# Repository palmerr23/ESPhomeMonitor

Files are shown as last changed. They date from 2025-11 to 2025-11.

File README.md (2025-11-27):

# ESPhomeMonitor
Hardware for monitoring equipment using HomeAssistant and Raspberry Pi Pico W-based ESPHome installation.

The boards described here are intended to be stacked, with the main Pico W board on top.

A 3D printable case is provided, with custom escutcheons for each input or output board type.

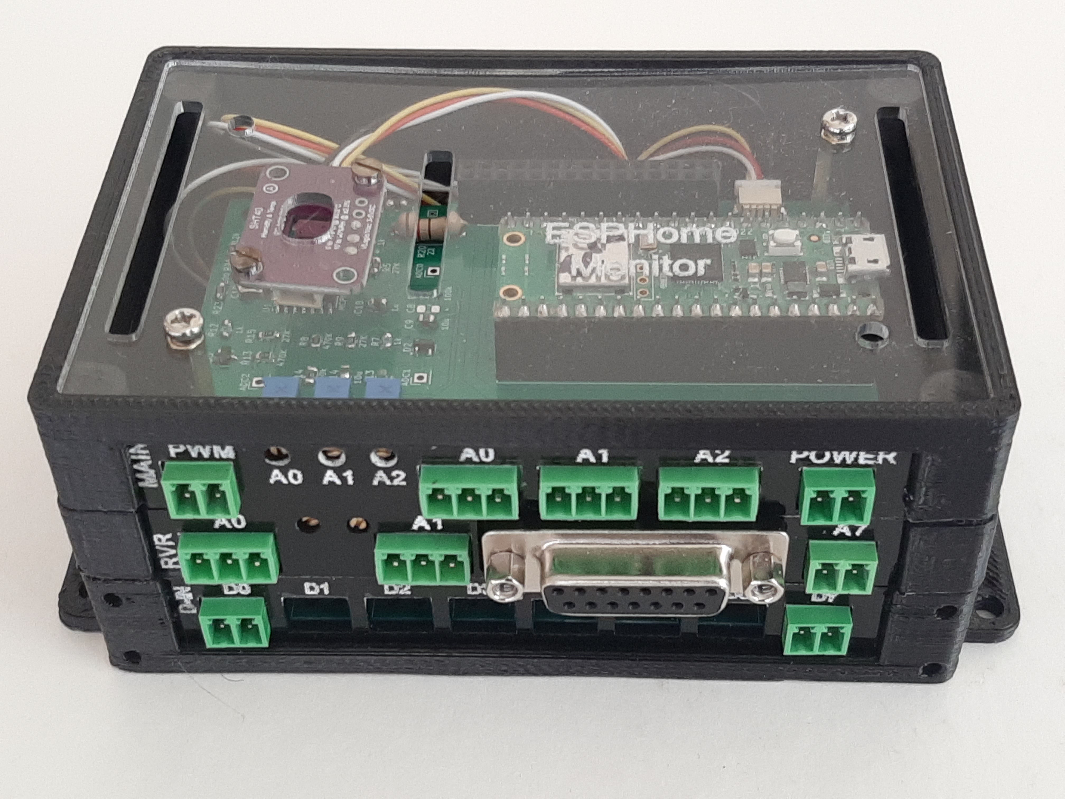
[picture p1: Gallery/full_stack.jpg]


# Boards
+ Main: Pico W, 3 x peak reading analogue inputs (400mV - 48V), filtered PWM output.
+ Analog Input: 8 x analog inputs (3.5V - 48V) 3.81mm pluggable terminals or IDC connector.
+ Analog Input (RVR): A specialised analog input board for RVR TEX150 transmitters and TXRL/RXRL STL.
+ Digital Input: eight channels, opto-isolated or non-isolated. 3.81mm pluggable terminals or IDC connector.
+ Digital Output: eight channels, 4 x opto-isolated + 4 x relays, or non-isolated. 3.81mm pluggable terminals or IDC connector.
+ Expander Board: Second stack and additional 3.3V regulator.

The boards are designed in KiCAD. Gerbers and KiCAD source files are provided.

# Case
A modular, 3D printable case is provided.
+ Base with strain relief.
+ Mid section for additional input and output boards
+ Top section for main (Pico) board.

Each board type has a customised escutcheon panel that slots into the case, designed to be laser-cut from 2mm acrylic.

The case has a top panel with ventilation and mounting points for a SHT-40 I2C temperature and humidity sensor.

The case is joined together with 12mm tapped spacers and 15mm for the main Pico board.

Case files are in STL (body) or SVG (cover and escutcheons) format.

# Documentation and configuration 

+ Technical overview (HomeAssistant Monitoring and Control.pdf)

+ KiCAD design files and an example ESPHome configuration file for each board. 

+ HomeAssistant dashboard configuration is left to the constructor as needs will differ.

ESPHome and HomeAssistant documentation is regularly updated for both platforms:
https://www.home-assistant.io/
https://esphome.io/

The HomeAssistant community forum is a useful place to search for problem resolutions on both platforms.
https://community.home-assistant.io/

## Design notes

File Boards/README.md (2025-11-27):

# ESPhomeMonitor Boards

# Boards

+ Main: Pico W, 3 x peak reading analogue inputs (400mV - 48V), filtered PWM output.
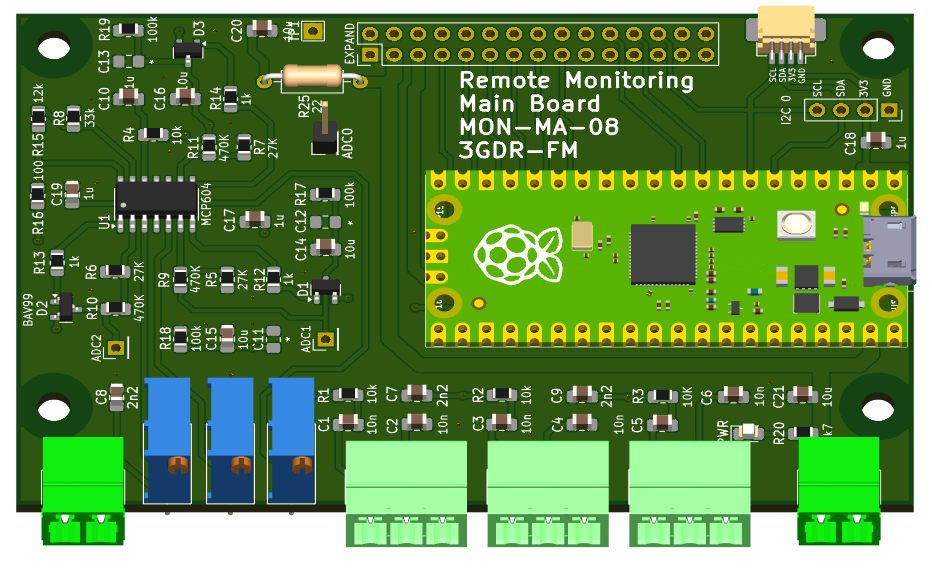
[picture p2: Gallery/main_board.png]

+ Analog Input: 8 x analog inputs (3.5V - 48V) 3.81mm pluggable terminals or IDC connector.
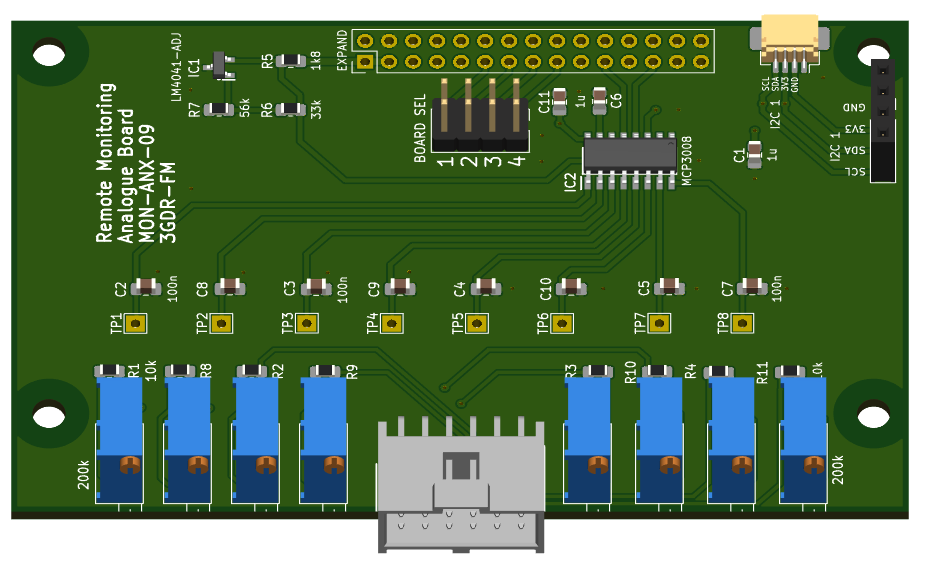
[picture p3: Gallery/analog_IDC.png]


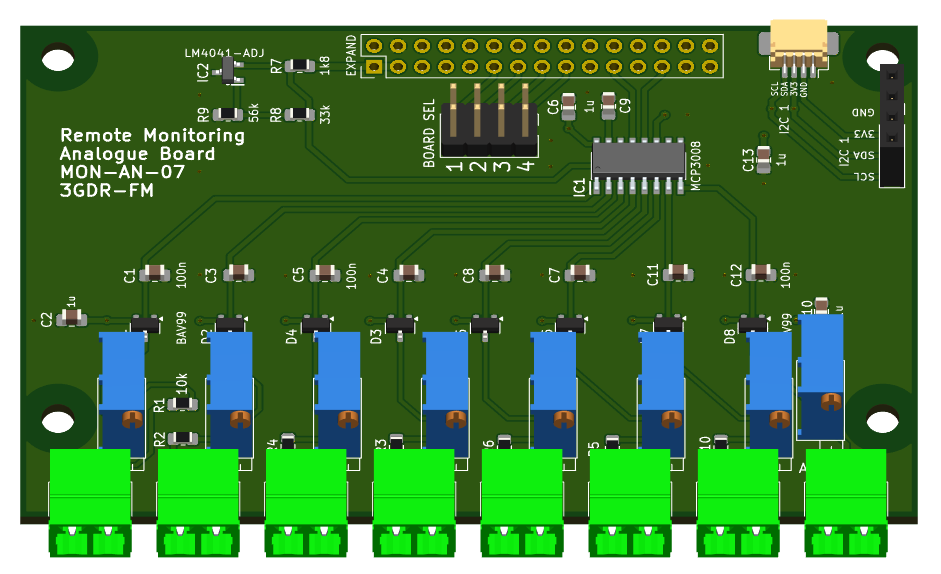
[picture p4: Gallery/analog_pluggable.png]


+ Analog Input (RVR): A specialised analog input board for RVR TEX150 transmitters and TXRL/RXRL STL.
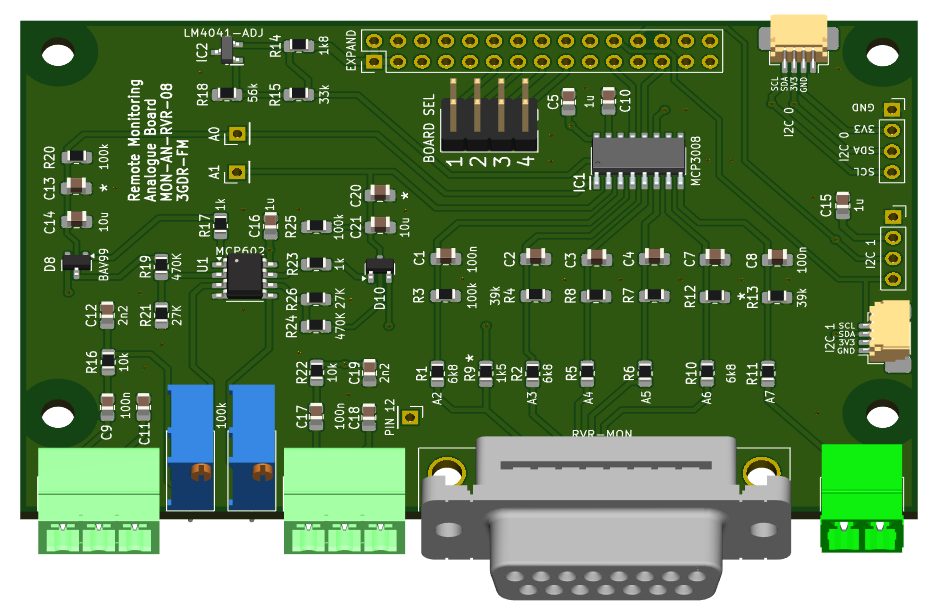
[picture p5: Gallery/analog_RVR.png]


+ Digital Input: eight channels, opto-isolated or non-isolated. 3.81mm pluggable terminals or IDC connector.
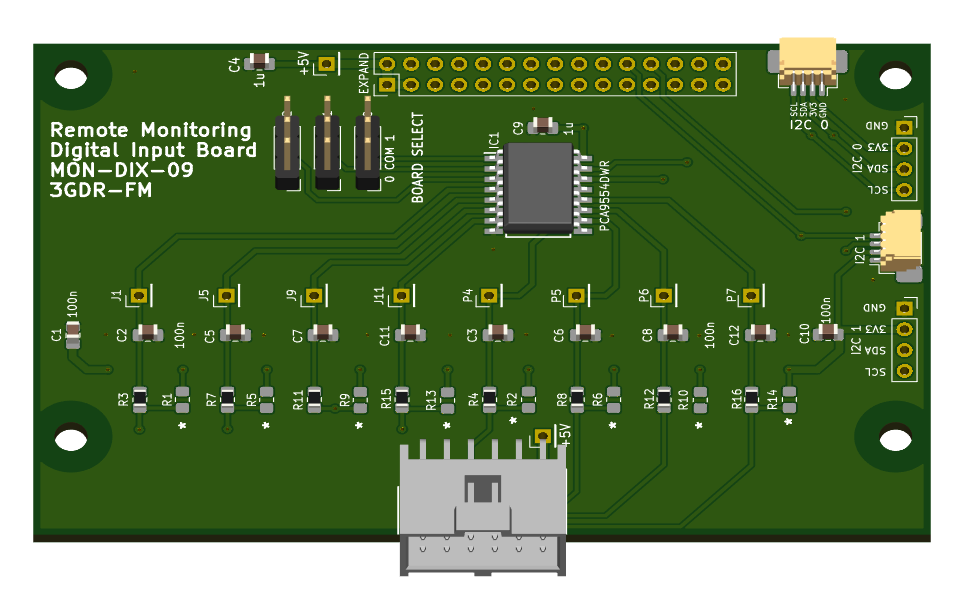
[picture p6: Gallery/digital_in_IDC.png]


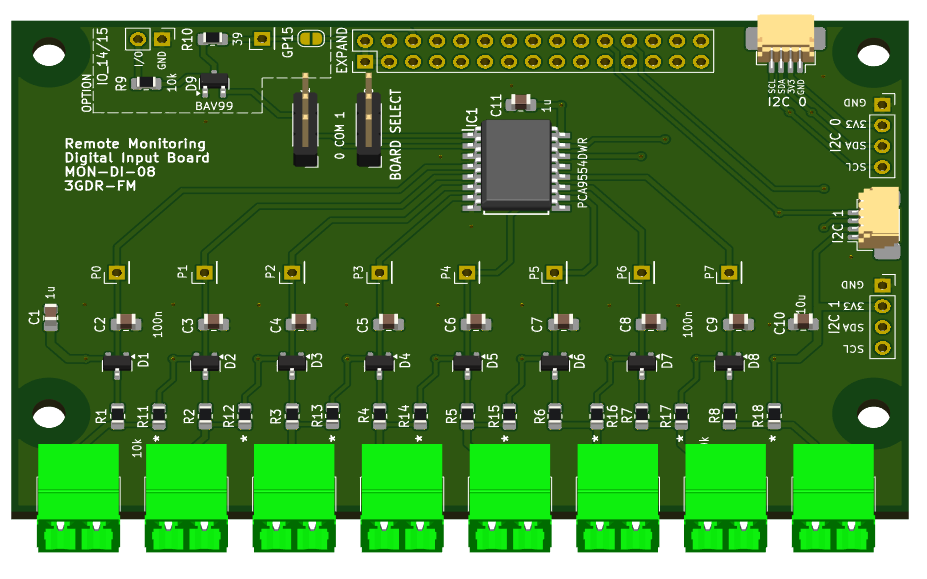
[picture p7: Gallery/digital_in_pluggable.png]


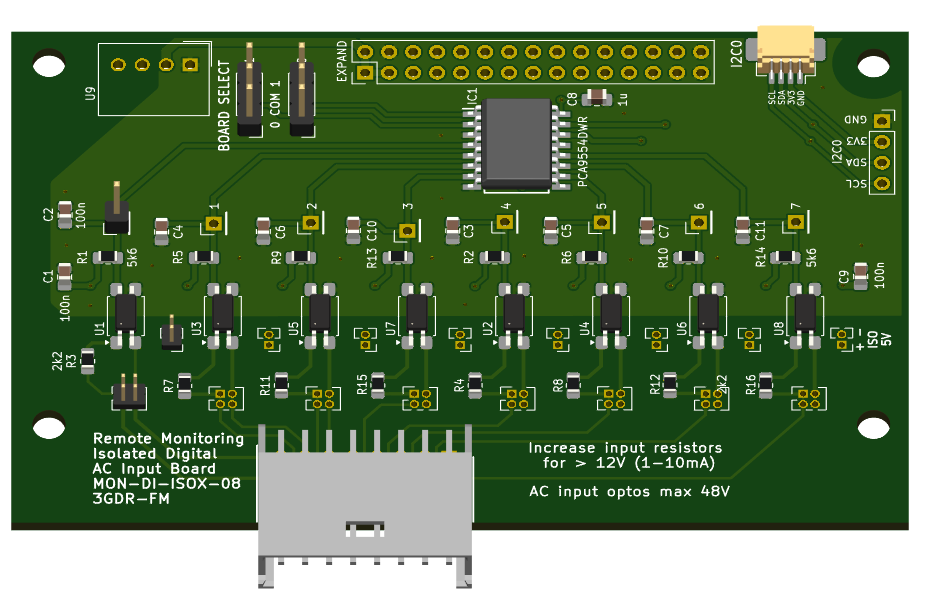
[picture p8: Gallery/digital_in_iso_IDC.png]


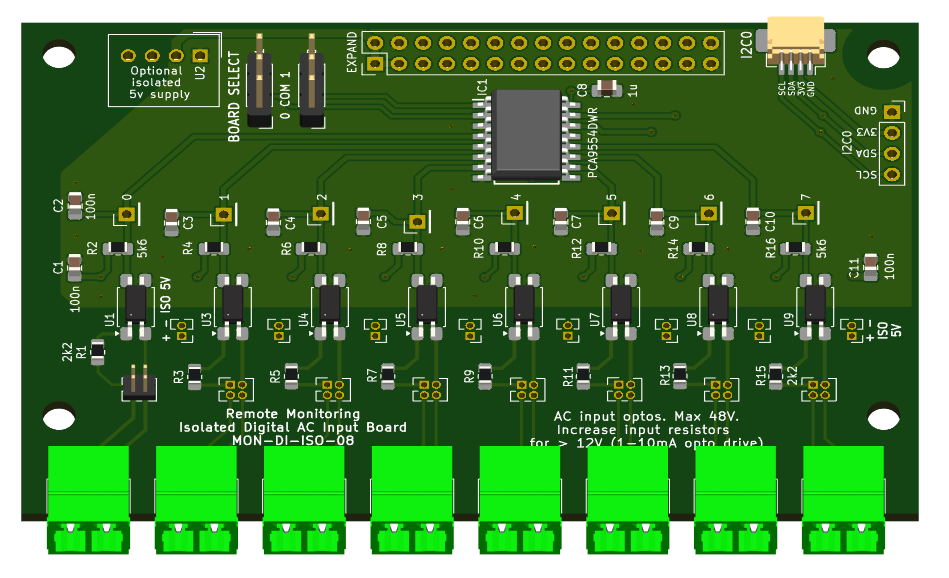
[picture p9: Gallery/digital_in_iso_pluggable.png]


+ Digital Output: eight channels, 4 x opto-isolated + 4 x relays, or non-isolated. 3.81mm pluggable terminals or IDC connector.

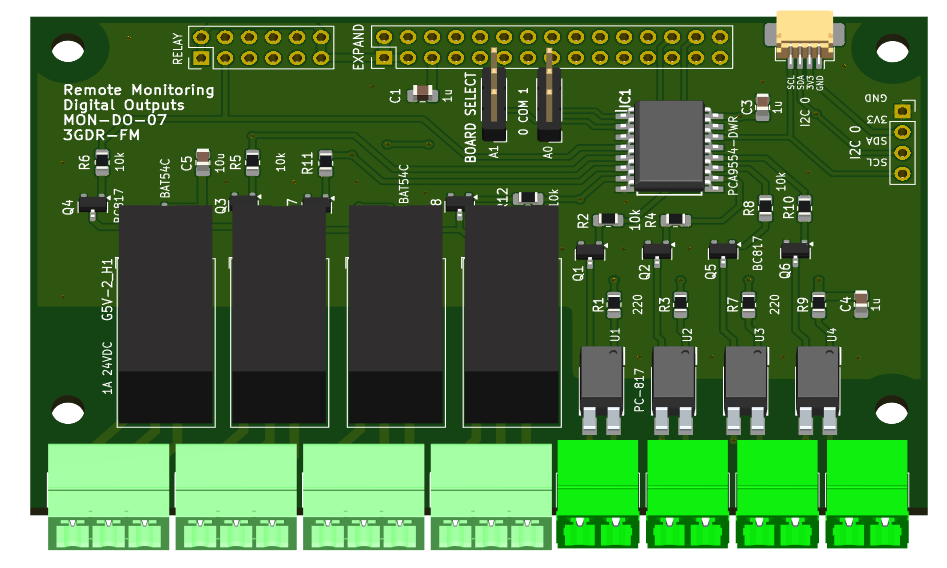
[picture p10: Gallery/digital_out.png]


+ Expander Board: Second stack and additional 3.3V regulator.

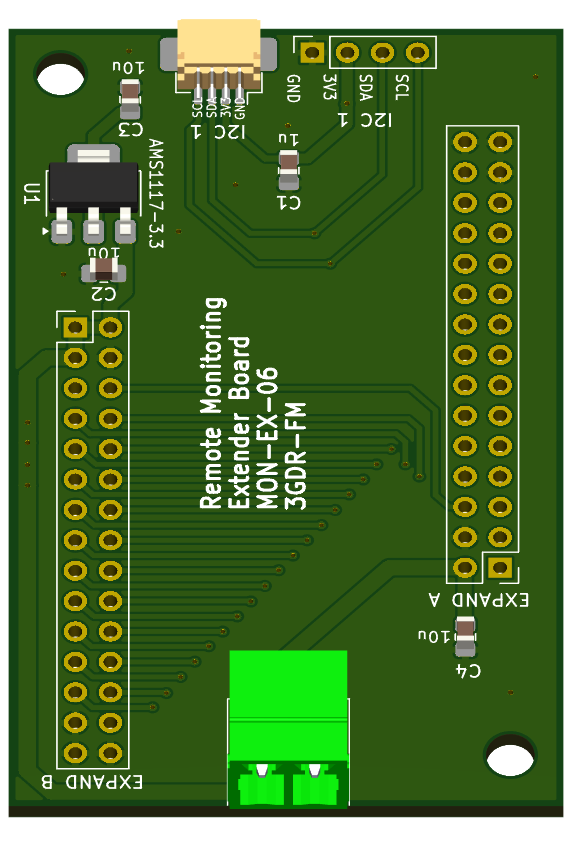
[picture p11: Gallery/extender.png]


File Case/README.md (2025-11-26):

# ESPhomeMonitor Case

The case was designed for 3D filament printing, however resin printing should be OK.

It has three sections: bottom, top and the required number of middle sections.

Top cover and escutcheon pieces are 2mm acrylic.

The base has optional strain relief provided by a length of 3mm bar bent into a U-shape and secured by two bar-holder pieces and 3mm screws and nuts.

The board at the bottom of the case has the long expansion pins on the underside removed.

## Escutcheon pieces 
+ Squeegee white paint into letters on top surface before removing either protective sheet.
+ Remove rear protective sheet and spray paint black.
+ Remove front protective sheet and clean up any extra white paint. Adhesion will be slight, so a soft plastic scraper or fingernail should suffice.

## Top cover

+ Squeegee paint into letters on bottom surface before removing either protective sheet.
+ Remove protective sheets and clean up extra paint.
+ SHT40 mount requires 2.5mm screws and nuts.

## Assembly

+ 12mm x 3mm  tapped spacers between boards.
+ 15mm x 3mm tapped spacer between Pico and top cover.
+ Mount escutcheons over boards before fitting to case. They slide into grooves in the fornt of the case.

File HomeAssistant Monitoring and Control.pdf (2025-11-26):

V1.0 Nov 2025

# PLATYPUS

# IoT Monitoring and Control

This suite of hardware comprises a Raspberry Pi Pico W-based ESPHome main board and a set of stacking daughter boards that support a range of sensor inputs and control outputs appropriate for the monitoring and control of remote equipment, such as a community radio station’s control room or transmitter site.

One or more ESPHome stacks can be connected to a HomeAssistant IoT management base station.

The design is modular and individual boards are stackable.

An Extender board is provided so that stacks can be split into two parts. Alternately, split stacks can be joined with an IDC cable. Cabling to boards using SPI should be kept as short as possible and the SPI frequency kept modest (1MHz) for reliable operation.

While all required sensor and control boards may be stacked on one ESPHome main board, creating several stacks for specific purposes may make more sense for power supply, redundancy, maintenance or operational reasons.

Specific monitoring hardware is included for RVR radio transmission equipment, specifically the TEX150 series of FM transmitters and the PRTL-LCD/RXRL-LCD series of RF studio transmitter links.

The information in this manual is current for:

- Raspberry Pi Pico W – only versions with the CYW43455 WiFi chip are currently supported (Nov 2025).
The Pico 2 W has no formal support at the time of writing (Nov 2025).
- HomeAssistant 2025.11 (HAOS 16.3)
- ESPHome Builder 2025.11

As both HomeAssistant and ESPHome have rapid update cycles, with bug correction based on user feedback, updates should be carefully considered and tested before being applied to the production platform.

Implementation and operation instructions for HomeAssistant and ESPHome are not duplicated in this documentation and community support are available at:

- https://www.home-assistant.io/ and https://community.home-assistant.io/
- https://esphome.io/ and https://community.home-assistant.io/

The repository for this project is: https://github.com/palmerr23/ESPhomeMonitor

- Schematics and board layouts
- Gerber files
- Documentation

## Contents

## Base Station and Satellite

The following components are used in this implementation from among the many available on the ESPHome and HomeAssistant platforms.

- Raspberry Pi running HomeAssistant (HAOS) OS.
- Remote control, monitoring, configuration and updating of HA and ESPHome devices.
- TailScale VPN for remote access.
- Raspberry Pi RP2040 Pico W running ESPHome firmware (Pico 2 W is untested).

### Sensors and Actuators

- See ESPHome.io for all supported devices.
- Analogue – Pico ADC pins and MCP3008 SPI ADCs.
- Digital input and output – PCA9554 series I2C bus expanders.
- SHT4x temperature and humidity sensors (I2C).
- See HomeAssistant.io for all supported devices
- USB webcams (FFMPEG).
- Some IP cameras with ONVIF compatibility (some cameras advertising ONVIF compatibility have failed to register).
- Remote access using TailScale VPN

## ESPHome Stack Overview

### General

- Flexible configuration to suit different needs
- Multiple stacks supported by one HomeAssistant hub on each wireless LAN.
- Flexible connector options:
3.81mm pitch pluggable terminals (Kefa KF2EDG or compatible)
IDC cable
D-sub (for RVR equipment) connectors.
- Single 5V @ 1A supply.

### Main Board

- Pico W running ESPHome OS.
- WiFi connection to HomeAssistant base station.
- 3 channels of peak indicating analogue inputs 400mV p-p, or greater, FSD. Single-ended or pseudo-differential inputs.
- QWIIC connector and pin header for I2C_0.
- Analogue (filtered PWM) 5V output.
- Expansion connector for stacking or daisy-chaining boards.

### Analogue Input Boards

- Eight single-ended analogue channels 3.3V, or higher, FSD.
- Two connector options:
- Pluggable 3.81 terminals
- 12-pin IDC header (3.3V and 5V power)
- QWIIC connectors and pin headers for primary and secondary I2C buses (I2C_0 & I2C_1).
- Four analogue boards (including RVR) maximum, in each stack.

### Analogue Input Board (RVR-specific)

- Eight analogue channels 3.3V, or higher, FSD (set to 4V FSD).
- 6 connected to RVR-compatible DB-15 female connector.
- Jumper from Pin 12 to A1 analogue input for STL MPX signal.
- QWIIC connectors and pin headers for primary and secondary I2C buses (I2C_0 & I2C_1).
- Four analogue boards (all types) maximum, in each stack.

### Digital Boards

- Digital input and output boards use PCA9554 or PCA9554A chips.
- Up to a total of four boards of each chip type can be used in a single stack.

### Digital Input Board - Isolated

- Eight opto-isolated AC inputs (3.3V-12V) with low drive current requirement. Higher input voltages supported with external current-limiting resistors.
- Two connector options:
- Individual 3.81mm pluggable terminal pairs
- 16-pin IDC connector (with optional isolated 5V power).
- QWIIC connectors and pin headers for primary and secondary I2C buses (I2C_0 & I2C_1).
- I2C addresses vary across the compatible chips.
- Four digital boards of a chip type supported in each stack.

### Digital Input Board (non-isolated)

- High impedance (10k) inputs (3.3V-12V).
- QWIIC connectors and pin headers for primary and secondary I2C buses (I2C_0 & I2C_1).
- I2C addresses vary across the compatible chips.
- Four digital boards of a chip type supported in each stack.

### Digital Output Board

- Four SPDT relay outputs (G5V: 1A @ 24VDC), with bypass for external power relays.
- Four opto-isolated outputs.
- Relays and optos may be bypassed if non-isolated connections are acceptable.
- QWIIC connectors and pin headers for I2C_0 & I2C_1.
- Four digital boards of each chip type supported in a stack (I2C addresses vary across the compatible chips).

### Extender Board

- Two back-to-back stacks.
- Alternate 5V supply input.
- Alternate 3.3V regulator for B-connector.
- I2C connectors for I2C_0 & I2C_1.

* The Mains Power Board and Serial Board have not been extensively tested.

### Case

- The modular 3D-printed case comprises
- Base with cable management bar and mounting flanges (4mm screws).
- One middle section per module
- Top section for Main Board (with extra clearance)
- 3mm laser-cut lid with SHT40 environmental sensor mount
Cover plates
- Each module has a 2mm laser-cut side cover plate.
- The cover plates fit into slots in the case.

## Warnings

- Updates should be carefully considered before being applied to HomeAssistant or ESPHome as breaking changes may have been introduced.
- ESPHome Builder and HA updates should only be applied when full testing of the results is convenient.
- A HA backup should be performed before any HA update.
- It is recommended that auto-updates are NOT enabled for add-ons.
- While some inputs and outputs are opto- or relay-isolated, potentials more than 48V different from the board’s ground plane should be avoided.
- Beware fouling the board above if the main (CPU) board is not mounted at the top of a stack.
- When connecting multiple stacks using an IDC cable, care should be taken to ensure correct orientation. Incorrect orientation will connect 5V to GND (pins2 & 4, 27 & 29).
- When selecting output components, consider the start-up behaviour of the ESPHome controller and the RP2040 for connected devices that should receive a known signal at power on.
- Excessive capacitance on the 3.3V supply rail can prevent the Pico starting up correctly. Four boards with 1uF each has proven reliable.
Earthing
Lack of a consistent ‘technical ground’ potential across studio or transmission equipment can cause issues when monitoring is introduced.
- Use opto-isolated digital inputs when ground potentials differ.
- Capacitor couple the ground (unbalanced) or negative (balanced) pin of audio signals being monitored.
- Consider using a separate stack, run from a different 5V supply, if issues persist.

### Table 1: Function Matrix

Board | Inputs or Outputs | I2C | Other
Main (CPU) | 3 x peak detectors (DB9-F) [ADC_0-2] 5V PWM outputs [GPIO 22] | I2C_0 (QWIIC + Header) [GPIO 4 & 5] | 5V power(pluggable) 3.3V @ 250mA supply for other boards
Analogue Input (SPI) 4 boards | 8 x inputs with gain control 12-pin IDC (with +3.3V +55 power) or 3.81mm pluggable terminal options | I2C_0 (QWIIC + Header) I2C_1 (QWIIC + Header) [GPIO 6 &7] | 4 analogue boards maximum per satellite. MCP3008 ADC
Analogue Input (SPI) (RVR adapted) 4 boards | 5 x inputs (DB15-F) 1 x input (pluggable) 2 x peak detectors (2 pin pluggable)
Digital Input (I2C) 4 boards | 8 x direct inputs 14_pin IDC or pluggable terminal options | I2C_0 (QWIIC + Header) | 4 digital boards (input + output) per satellite. May be increased to 8 if PCA9554 and PCA9554A variants are both
4 boards | 8 x AC-input opto-isolated 14_pin IDC or pluggable terminal options Optional isolated 5V supply | I2C_0 (QWIIC + Header) | used. Isolated Digital Input (I2C)

Isolated Digital Output (I2C) 4 boards | 4 x SPDT relay (3 pin pluggable) 4 x opto-isolated (2 pin pluggable) | I2C_0 QWIIC + Header
Non-isolated Digital Output (I2C) 4 boards | 8 x 3.3V digital outputs. 14_pin IDC or pluggable terminal options | I2C_0 QWIIC + Header
Extender | | I2C_0 (QWIIC) I2C_1 (QWIIC + Header) | Alt 5V power input (header or wired) Additional 3.3V regulator option for second stack.

## Stacking PCBs

Stacking PCBs is enabled by mounting 30-pin female headers with long pins on the Expansion connectors of each board. The gap between boards is 12mm (13.6mm including the PCB), which is sufficient to clear the PCB-mounted D-SUB connectors but not the Pico when it is mounted in a header.

When stacking boards, the CPU board should be at the top so that WiFi transmission is unimpeded and so that the top of the Pico does not foul the board above when mounted on a header.

Metal enclosures or lids should be avoided.

Power consumption should be taken into account when stacking boards. The Isolated Digital Out board, particularly, has significant power consumption (480mA @ 5V) with all outputs engaged. If one or more Isolated Digital Output boards are used, the pluggable socket on the Main or Extended board should be used to supply power to the system.

The Pico is capable of supplying 250mA to other boards. If greater current is required, the Extender Board has an optional 3.3V regulator which can supply a second stack.

Boards using the SPI bus should be kept as close to the CPU as practical. The SPI clock speed can be reduced if this is not feasible.

Multiple stacks, sharing a CPU, can be joined using the Extender Board or a 30-pin IDC cable (male or female). Ensure that pin 1 on each stack correctly aligned.
3D printable case
The 3D printable case is designed for a single stack, not using the Extender board.

The bottom-most module should have short pins on the expansion header.

Modules are stacked using 3mm x 12+6mm tapped spacers.

The bottom module is mounted from below the case with 3mm x 8mm metric round head screws and uses a 3mm x 12mm spacer tapped at both ends.

The top module uses a 3mm x 15 + 6mm spacer and the lid is screwed to this, securing the case. It has sufficient clearance for the Main module with the Pico W mounted on headers.

## Part substitution

- Main board pp amps are rail-to-rail, 5V single rail devices with low input currents. Gain-bandwidth product is not critical except in the peak detector circuits where the slew rate contributes to the rise time. Op amps with internal protection diodes protection should be used.
- Either PCA9554 and PCA9554A I2C Bus Expanders may be used in the digital input and output boards. Note that they have different I2C address ranges.
- Pico W: Pico 2 W microcontroller modules are not yet fully tested under ESPHome.

## ESPHome Configuration

Information in the ESPHome documentation is referenced, but not repeated here.

### Startup and Restart Behaviour

During the ESPHome power-on sequence the state of various peripherals is determined by the RP2040 startup behaviour:

- All GPIOs are reset to pull-down state (~50k ohms to GND).
- Soft pull-ups will not be operating on inputs.
- Opto-isolated outputs will be set to open-circuit.
- Peripherals (I2C, SPI, etc) are inactive.
- Analogue outputs (PWM) will be at 0V, although a start-up spike may occur.
- Analogue inputs will have undefined values until the input offset voltage has settled. (~20mS)

After an ESPHome software restart, until the firmware becomes active:

- The ESPHome documentation is unclear on the value of GPIO outputs (GPIO Switch) during startup.
- Analogue outputs (PWM) will temporarily sink towards 0V.
- Peripherals (I2C, SPI, etc) are inactive and will be reset.

When HomeAssistant is unavailable:

- All ESPHome output states remain stable as there are no local ESPHome automations.
- Local ESPHome lambda code continues to run (e.g., serial port logging).
- ESPHome display devices will not be updated if the values are supplied by HomeAssistant.

## ESPHome Main Board

This board should be placed at the top of the stack if the Pico W is mounted on top of the board. WiFi coverage is improved and the Pico, when mounted on headers, can foul the underside of the board above it on the stack.

Alternately, the headers can be placed on the rear of the board, and the pins mounted on the top of the Pico instead of underneath. This configuration is particularly useful for testing daughter boards.

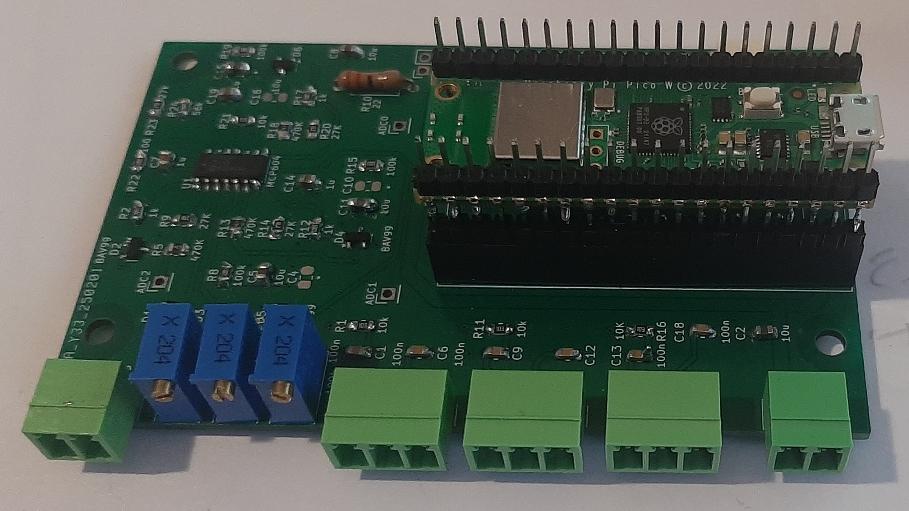
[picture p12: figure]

Boards using SPI should be in the same stack (e.g., power and analogue input) as the CPU board or on a very short IDC extender cable. The default SPI data rate is 1MHz, which can be slowed down further if these boards behave erratically.

The main board hosts the Raspberry Pi Pico W as well as three overvoltage protected, pseudo-differential, peak detecting analogue inputs broken out to a 3-pin 3.81mm pluggable terminals. Their FSD is trimmable via potentiometers from 400mV p-p to more than 12V.

Voltages > 48V should not be applied.

A PWM signal is available via the 2-pin 3.81mm pluggable terminal next to the pots.

Power can be supplied via the Pico’s USB connector or through the 2-pin 3.81mm pluggable terminal at the same end of the board as the Pico’s USB connector.

The Pico W can provide 3.3V up to 250mA to power logic on other boards in the stack. If more current is required, the Expansion board offers a second 3.3V regulator to power a second stack of daughter boards.

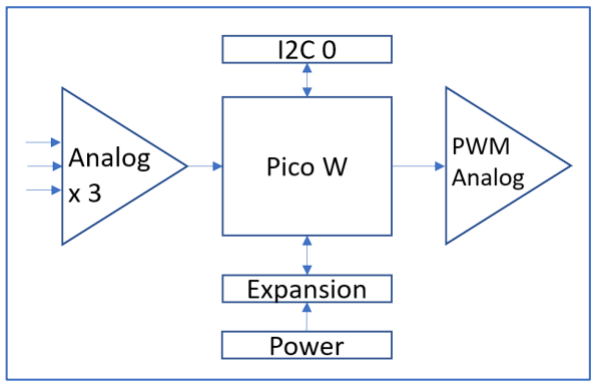
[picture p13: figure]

Main Board Block Diagram

### Expansion Header

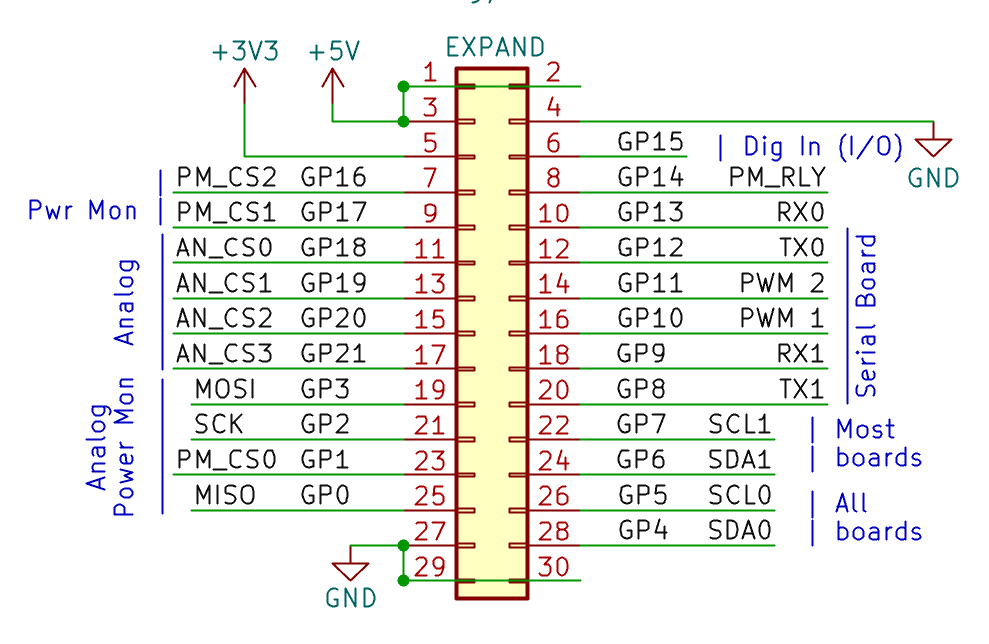
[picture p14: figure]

Expansion header
Table 2: Expansion Header Pins
Pin | Signal | Uses | Pin | Signal | Uses
1 | +5V Power | | 2 | +5V Power
3 | +5V Power | | 4 | GND
5 | +3.3V (250mA tot) | | 6 | GP15* | Dig In I/O
7 | GP16* | Pwr Mon CS2* | 8 | GP14* | Power Monitor Relay
9 | GP17* | Pwr Mon CS1* | 10 | GP13, UART0 RX* | Serial
11 | GP18 | Analog Board SEL0 | 12 | GP12, UART0 TX* | Serial
13 | GP19 | Analog Board SEL1 | 14 | GP11 | Opt. Serial PWM 1
15 | GP20 | Analog Board SEL2 | 16 | GP10 | Opt. Serial PWM 2
17 | GP21 | Analog Board SEL3 | 18 | GP9, UART1 RX* | Serial
19 | GP3, SPI0 MOSI | Analog, Power Mon | 20 | GP8, UART1 TX* | Serial
21 | GP2, SPI0 SCK | Analog, Power Mon | 22 | GP7, SCL1 | Analog, Extender
23 | GP1 | Power Monitor SEL0 | 24 | GP6, SDA1 | Analog, Extender
25 | GP0, SPI0 MISO | Analog, Power Mon | 26 | GP5, SCL0 | Digital In and Out,
27 | GND | | 28 | GP4, SDA0 | Digital In and Out
29 | GND | | 30 | GND
* GPIO 15 is uncommitted in this design.

* GP 0, 1, 8, 9, 12, 13, 14, 16 & 17 may be used for other purposes if the Serial and Power Monitor boards (planned developments) are not used.

### Inputs and Outputs

I2C
Pin assignments are:

SDA 0 GP4
SCL 0 GP5

SDA 1 GP6
SCL 1 GP7

Pull-ups are present on the main board for both I2C buses.

I2C 0 is available on the main board both as a QWIIC (STEMMA QT / Grove / PiicoDev / etc) four-pin JST-SH 1.0mm connector and a four pin 0.1” header.

I2C 1 signals are available via the expansion header on the analogue and digital input boards and the extender board.

SPI
SPI0 is available via the expansion header. CS pins are managed via software.

The Analogue Input boards and Power Monitor boards use SPI.

GP0 | MISO
GP2 | SCK
GP3 | MOSI
GP18-21 are allocated to CS signals for up to four analogue input boards. GP1 is allocated to CS for the (future) power monitor board.

All SPI pins may be reallocated if not required.

UARTS
Both UARTS are presented to the expansion header. They are configurable to any modes and data rates supported by the Pico.
GP8 | TX1
GP9 | RX1

GP12 TX0
GP13 RX0

The pins may be re-allocated if UARTS are not required.

GPIO
GPIOs 15 is available on the expansion header and not used by any of the existing daughter boards – see Table 3.

Any other uncommitted pins on the expansion header may also be used as GPIO inputs or outputs. The constructor needs to take responsibility for protecting the Pico against excessive and reverse voltages. While the Pico’s inputs do include some protection, it is strongly advised not to rely solely on this.

The digital input and output boards include protection as well as providing options for opto-isolation of inputs and relay or opto-isolation of outputs.
Analogue Inputs
Three peak-detecting analogue inputs are available using the Pico’s ADC 0-2 (GPIO 26-28) with a basic FSD of 400mV, trimmable by on-board pots. These inputs translate to 0.0 – 1.0 in HomeAssistant. While the maximum count is 4095 (12 bits), the accuracy (ENOB) is around 9 bits (~512 counts, or 0.2% accuracy).

The inputs are pseudo-balanced and the sensitivity is controlled by the trim pot. The opamp gain is 17 which translates an un-trimmed 390 mV p-p op-amp input to 3.3V output.

If any channel is overdriven erroneous results may occur on other channels, particularly those with small input signals.

If single ended inputs are required, the remote device ground may be connected to the INx― pins or board ground, as desired.

The attack time constant is short (20mS) and the decay time constant is long (2 seconds). They can be changed by varying R2/C4+C5/R8, etc. The Pico’s analogue inputs have ~100k ohm input resistance, so increasing R8 will have limited effect on the time constant.

R1/C1/C2 tailor the frequency response is tailored to an extended speech band: 200Hz to 5kHz.

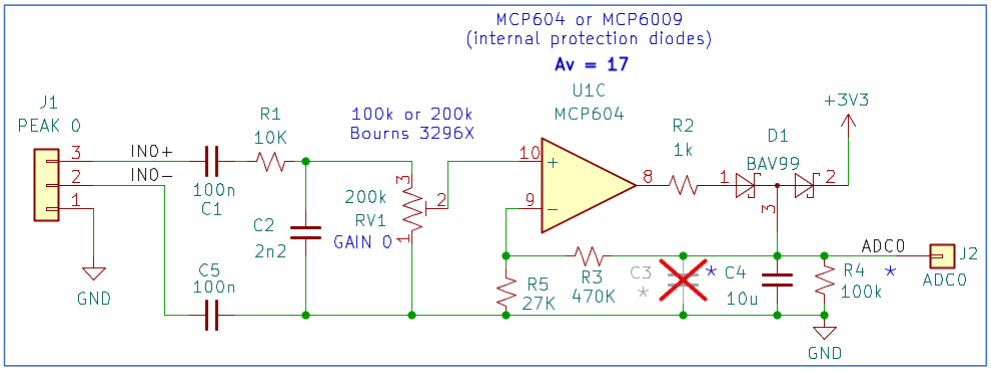
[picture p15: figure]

Example peak detector. C3 may be added to extend the decay time.

The op amps are rail-to-rail, 5V devices with low input currents. The slew rate (GBP) contributes to the rise time. The recommended MCP604 or MCP6009 op amps have internal protection diodes.

ESPHome documentation recommends that digital filtering is applied to all analogue inputs to avoid startup misreads and signal noise. Specifically, the ‘sliding window moving average’ and ‘skip initial’ filters are recommended and included in their example configuration code. https://esphome.io/components/sensor/#skip-initial

# Place in sensor: block

# Pico inbuilt ADC - Main board

- platform: adc
pin: 26
name: "ADC0"
update_interval: 10s
- platform: adc
pin: 27
name: "ADC1"
update_interval: 10s
- platform: adc
pin: 28
name: "ADC2"
update_interval: 10s

Peak Detector Response
The frequency response of the peak detector has been tailored to the speech band, approximating C-weighting.

0

1

2

3

0 | 0.5 | 1 | 1.5 | 2 | 2.5 | 3 | 3.5

Output (V)

Input (Vp-p)

### Peak Detector Response (1kHz)

Vo | Vread

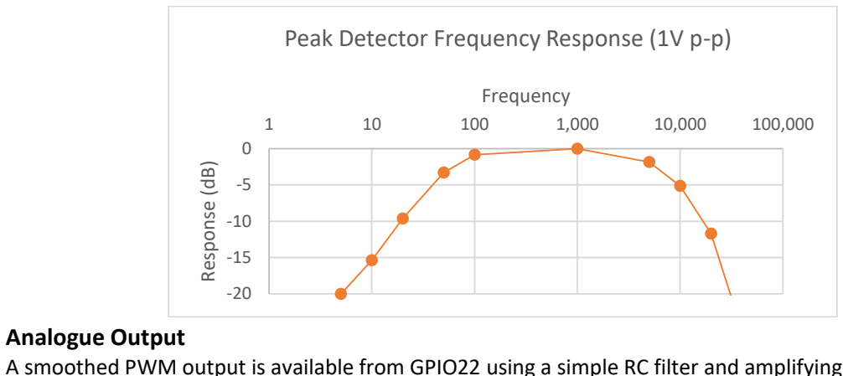
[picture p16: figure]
Analogue Output; Response (dB); Frequency

A smoothed PWM output is available from GPIO22 using a simple RC filter and amplifying buffer.

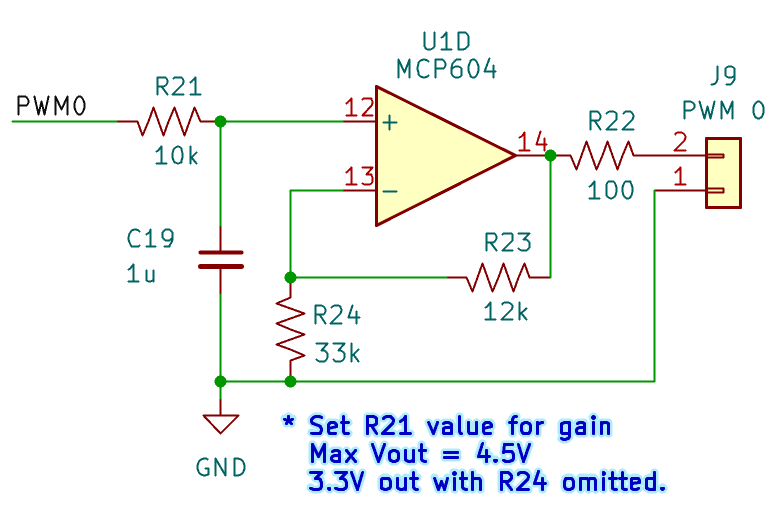
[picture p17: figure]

PWM output buffer

The maximum output level is 4.7V (VCC – 0.3V) with the values indicated for R32/R24 the output is 4.5V @ 100%. Omitting R24 sets the maximum output to 3.3V.

Setting the PWM frequency to 64kHz will provide 10 bits of accuracy and minimise output ripple.
At 64kHz and 50% duty cycle, the ripple is < 10mV p-p.

If lower ripple is required a 100n capacitor may be soldered across R15, providing a second filter pole.

The standard ‘monochromatic light’ platform is configured for linear LED brightness, so Gamma correction needs to be re-set to linear (1.0).

At start-up and restart, the signal will fall to zero.

# PWM output – Main board

output:
- platform: rp2040_pwm
pin: 22
id: PWM_22
frequency: 64000Hz
light:
- platform: monochromatic
output: PWM_22
gamma_correct: 1.0 # align output with pwm % name: "PWM"
id: pwm

Peak Detector Frequency Response (1V p-p)

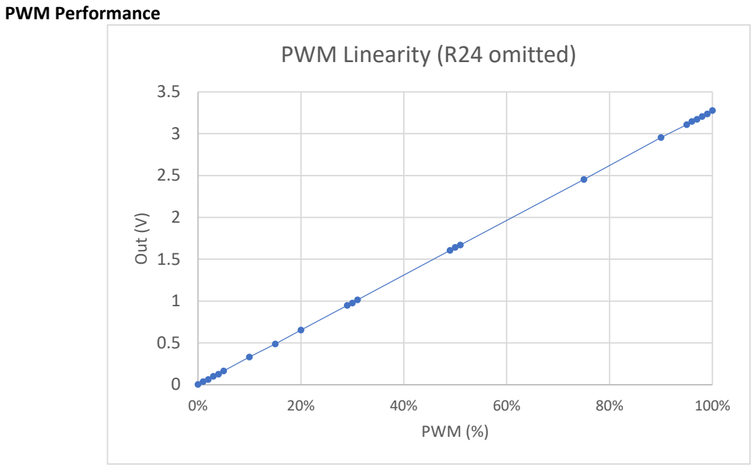
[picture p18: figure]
PWM Performance; Out (V); PWM (%); PWM Linearity (R24 omitted)

Deviation from linear response is < 7mV with a 3.3V FSD output.

### WiFi

The WiFi interface is reserved for communicating with the HomeAssistant base platform.

WiFi credentials are set in the ‘Secrets’ section of the ESPHome Builder tab on HomeAssistant. No additional configuration is required.

### Powering

The Main board consumes less than 20mA, excluding any consumption by devices attached to the I2C interface.

While the unit can be powered via the Pico USB socket for testing, it is recommended that an external regulated 5V supply be connected to the board PWR terminals. The required current can be determined from Table 3. There are additional 5V terminals on the Extender board.

The Pico is capable of providing 3.3V @ 250mA to other boards. If more current is required, a 3.3V regulator is available on the Extender Board which powers the second (B) stack.

### Configuration

The Pico should be configured as described in the ESPHome online documentation. A straightforward approach is to follow the instructions at https://esphome.io/guides/getting_started_hassio which allows firmware loading and configuration of the Pico W from the HomeAssistant browser window.

After the board has been configured and installed using ESPhome Builder, it must be brought on line from the HA Integrations screen.

### Table 3: Daughter Board Current Consumption

Board | 3.3V * excluding connected devices | 5V * excluding connected devices
Main | Can source 250mA | 20mA
Analogue In | 1mA | 5mA
Digital In | 5mA plus 10mA (all 8 optos active) | -
Digital Out | 5mA | 480mA (all 4 relays and 4 optos active)

* Add current drawn by I2C and other connected devices.

## Extender Board

If side by side operation is required, the extender board has two expansion connectors rotated 180⁰ and offset so that the two sets of boards are correctly aligned.

The board has additional 5V input pads.

An optional 3.3V regulator may be mounted on the expander board to power the ‘B’ stack. If this is configured, the Pico should be mounted on the ‘A’ connector and the links on the underside of the board adjusted.

## Analogue Boards

A-D Conversion is provided by an MCP3008 8-input 10-bit SPI ADC. https://esphome.io/components/sensor/mcp3008.html

Three versions are offered with different input connectors:

- 3.81mm pluggable terminals (trimmable on all channels)
- 12-pin IDC cable which also carries 3.3V and 5V power (trimmable on all channels)
- RVR equipment-specific with a DE-15 connector (trimmable peak detectors on channels 0 and 1)

SPI data rates are kept low (200kHz, default is 1MHz) to increase the effective ADC input impedance from 1k ohm to 10k ohm.

A-D Conversion is provided by an MCP3008 8-input 10-bit SPI ADC with 3.3v FSD.

CS jumpers are provided for up to four analogue input boards in a stack.

The native sensitivity of 3.0 V full-scale is decreased by the trimpot, and the 100n capacitor reduces transient sensitivity and provides a charge reservoir for the ADC sample and hold.

The ADC’s internal diodes protect from under and over voltage. R1 keeps the protection diodes within their 250mA current limit for up to 25V when the potentiometers are at their maximum setting.

The maximum recommended input voltage (with reduced gain) is -5V to +48V.

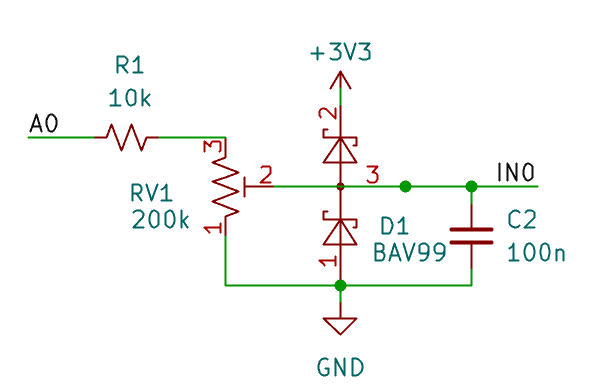
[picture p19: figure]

The LM4041-derived ADC voltage reference is set to 3.3V by resistors R10/R11.

Up to four analogue boards may be used in a stack, by jumpering CS to one of the dedicated expansion pins GP18-21 on the BOARD_SEL header.

### Analogue Input Board (pluggable terminals)

This board has eight single-ended analogue inputs. The ESPHome implementation does not support MCP3008 pseudo-differential mode, as of November 2025.

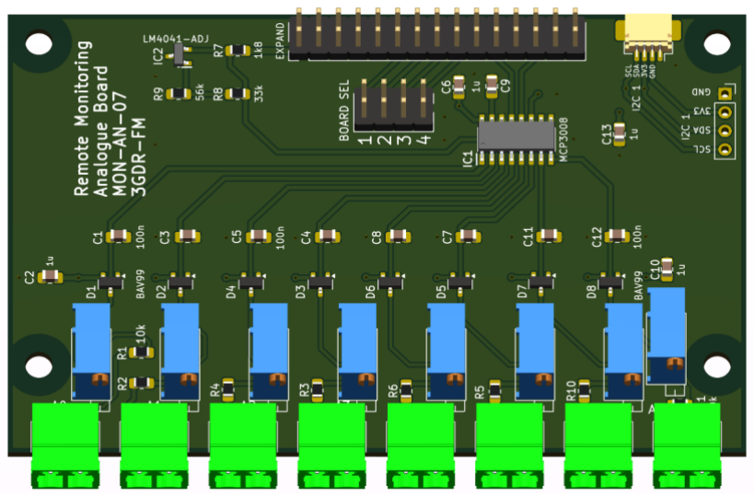
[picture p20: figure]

All inputs have configurable voltage dividers, with a basic sensitivity of 3.3V FSD.

The 100nF capacitors provide a low impedance source for the ADC sample and hold and reduce sensitivity to transients.

The inputs have gain trimmer potentiometers accessible between the input connectors.

CS jumpers are provided for up to four analogue input boards in a stack.

The inputs are presented as 2 x 3.81mm pitch, pluggable terminal blocks.
I2C
QWIIC connectors and pin headers are provided for I2C 1. Configuration
See configuration for the RVR Analogue Input Board.

### Analogue Input Board (IDC)

This board has the same circuit and configuration as the pluggable terminal option, with the inputs presented as a 12-pin IDC header.

3.3V and 5V supplies are provided to power any signal conditioning circuitry on the daughter boards.

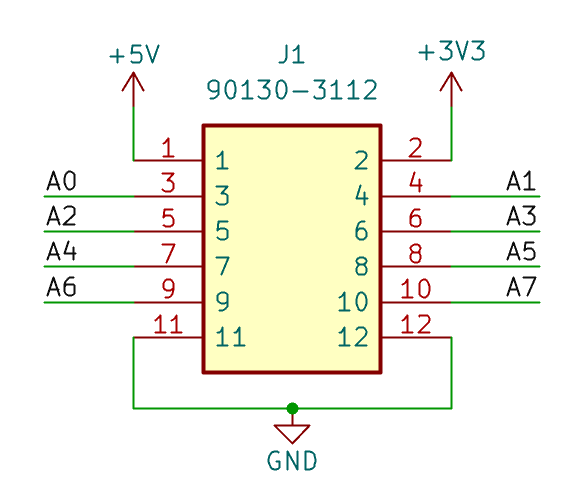
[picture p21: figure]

The IDC connector pin-out is compatible with the non-isolated digital input board.

### RVR Analogue Input Board

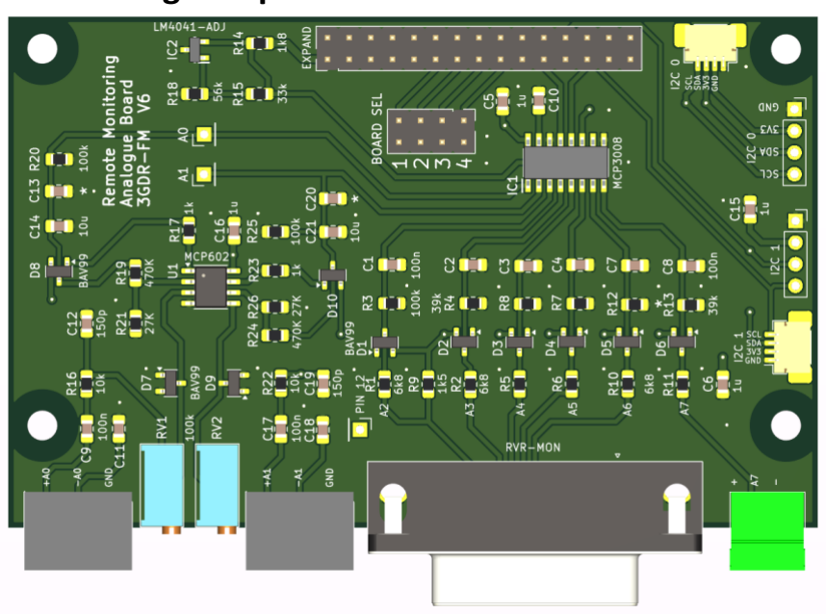
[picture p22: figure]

This board has been designed specifically to interface with RVR broadcast equipment which has a fairly standard monitoring and control interface, presented as a DB-15F connector.

It has five direct-reading inputs tied to specific pins of a DB-15F connector. The remaining DB-15 pins are left unconnected as they have other functions on RVR equipment.

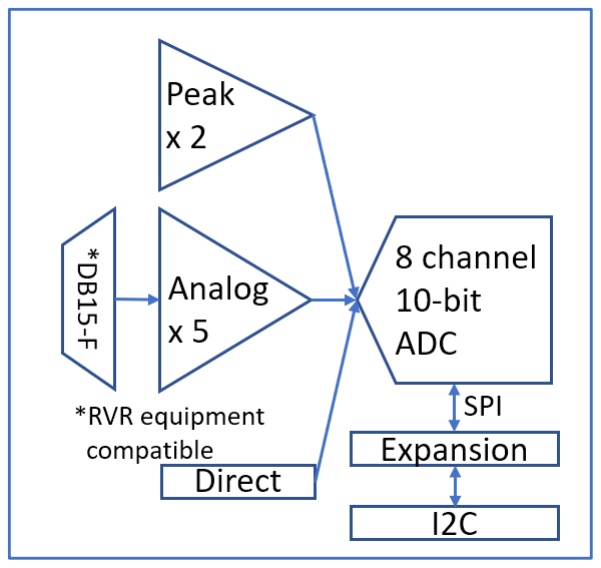
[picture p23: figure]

All inputs have voltage dividers with the default 22k gain resistors providing 3.9V FSD, compatible with RVR analogue monitoring outputs. The 100nF capacitors provide a low impedance source for the ADC sample and hold, and form a low-pass filter (F0 = 250Hz) with the 6.8k input resistors

RVR devices provide an open collector output (PWR_GOOD on transmitters and MUTING_TLS on STLs) on Pin 7 on the DB-15 connector. A pull-up resistor is provided to the 3.3V rail.

Pin 6 is a static analogue signal (PA_CURRENT) on transmitters and a dynamic signal (MPX_LEVEL) on STLs. A patch point to is provided for this signal to be connected to the A0 or A1 peak detectors, if desired.

Of the remaining three inputs, A0 and A1 are peak-reading – with the same configuration as the Main Board.

A0, A1(peak reading) and A7 are presented as 3.81mm pitch, pluggable terminal blocks.

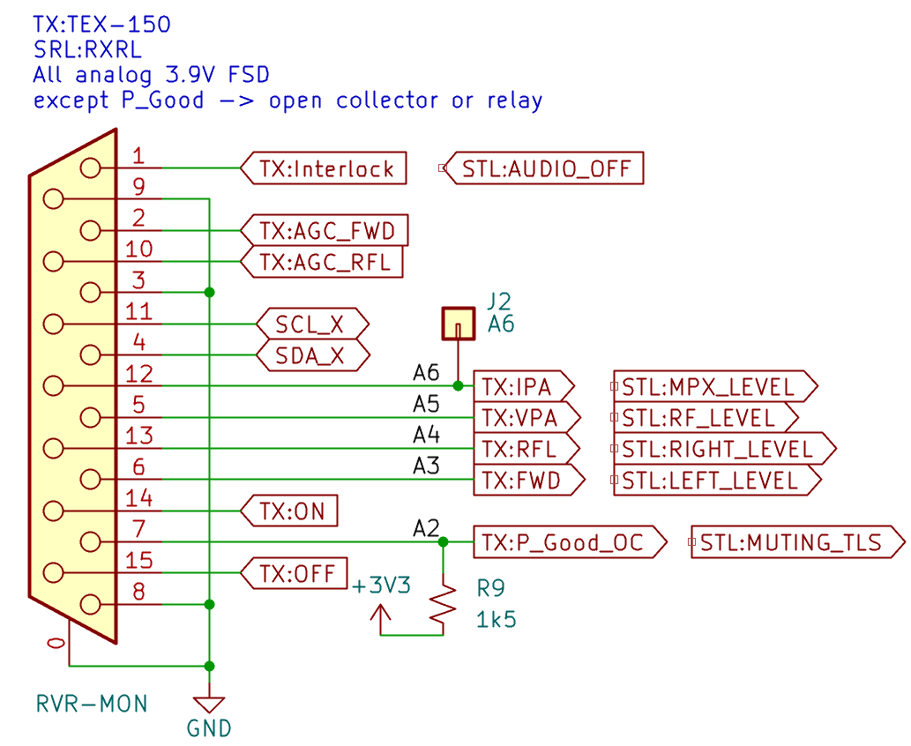
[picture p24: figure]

RVR equipment DB15 pinouts
Pin | RVR FM & STL Transmitter | RVR STL Receiver | Pin | RVR FM & STL Transmitter | RVR STL Receiver
1 | Interlock (control) | Audio Off (control) | 9 | GND | GND
2 | AGC FWD (control) | - | 10 | AGC RFL (control)
3 | GND | GND | 11 | SCL | SCL
4 | SDA | SDA | 12 | IPA | MPX LEVEL
5 | VPA | RF LEVEL | 13 | RFL | RIGHT LEVEL
6 | FWD | LEFT LEVEL | 14 | TX On (control) | -
7 | PWR_Good (OC) | MUTING (OC) | 15 | TX Off (control) | -
8 | GND | GND
- Signals in red are not connected.
- Analogue signals are 3.9V FSD, which represents 100% of the unit’s set value in most cases.
- Pin 7 signals are OC, active low. On-board pull-ups are provided.

The ESPHome documentation recommends that digital filtering is applied to analogue inputs. https://esphome.io/components/sensor/#skip-initial
Configuration

# Place in sensor: block

# Analogue input board

# Channel 0 of the MCP3008.

- platform: mcp3008
unit_of_measurement: "%"
reference_voltage: 3.0
update_interval: 5s
mcp3008_id: mcp0
name: "AD_B0_V1"
accuracy_decimals: 1
id: v1
number: 0
# scale to 100% from 3.3V ref filters:

- multiply: !lambda return 30; # Channel 1
- platform: mcp3008
reference_voltage: 3.0
update_interval: 5s
mcp3008_id: mcp0
accuracy_decimals: 2
name: "AD_B0_V2"
id: v2
number: 1
Auxiliary
QWIIC connectors and pin headers are provided for I2C_0 and I2C_1.

## Digital Boards

The digital input and output boards are compatible with the PCA9554 (and PCA9554A) series of I2C bus expander chips. I2C addresses vary across the range. Four chips sharing the same base address may be used in any stack.

Each board has eight inputs or outputs numbered 0 .. 7.

Inputs or outputs may be logically inverted by code.

https://esphome.io/components/pca9554.html Platform Configuration – all digital boards

pca9554:
- id: dig_in_0
i2c_id: i2c_a #I2C bus previously defined
address: 0x38 | // 0x38 .. 0x3F for Board 0 PCA9554A; 0x20 .. 0x27 for PCA9554
# additional input or output boards are added here:

### Digital Input Boards

Input Configuration
https://esphome.io/components/binary_sensor/

binary_sensor:
# on digital input board 0

- platform: gpio
name: "Input 0"
id: in_0_0
pin:
pca9554: dig_in_0
number: 0 | # 0 .. 7
mode:
input: true
inverted: false # (as required)
# additional inputs or outputs are added here

The ESPHome documentation recommends that digital filtering is applied to all inputs to avoid start-up misreads and signal noise. https://esphome.io/components/sensor/#sensor-filters

Digital Input Board (opto-isolated)
The digital input board has eight opto-isolated inputs which are presented as 2-pin 3.81mm pluggable terminal blocks or a single 16-pin IDC connector.

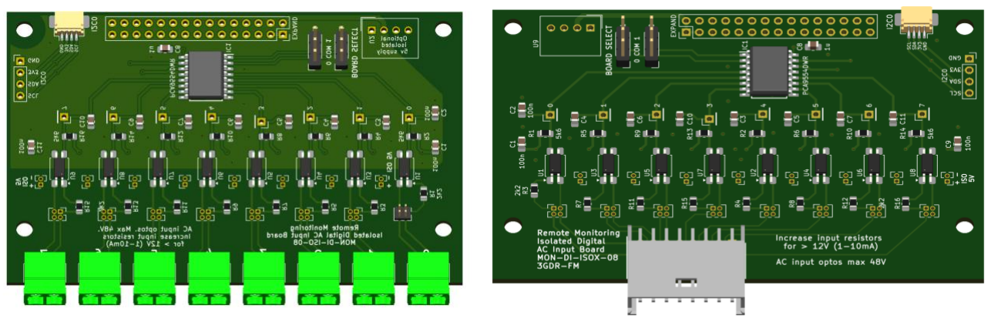
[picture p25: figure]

While the inputs are opto-isolated, potentials of more than 48V difference from the board’s ground should be avoided.

Opto-isolated inputs accept either polarity at a source current of 1mA or more, using AC input opto-couplers with a high (> 100% @ 1mA input) CTR (TLP292, TLP180GB or similar). The PCB footprints have wide pads that can accept either 1.27 or 2.54mm pin spacings.

Jumper blocks are provided to allow flexible configuration of the inputs, along with an access to an optional isolated 5V supply on the IDC variant. The input jumper blocks are linked by default, using fine tracks on the top of the board.

For instance, these jumpers and the isolated power supply may be used to sense a pulled-up switch-to-ground signal. 2.2k pullup resistor is inserted from Viso+ to pin 1 & 3; and Viso- connected to pins 2 & 4.

Both rails of the isolated supply need to be connected to some point in the sensed circuit.


A representative opto-isolated input. The left panel is the default configuration.
The jumpers 1-3 &/or 2-4 may be broken to connect the isolated 5V supply to either pin.
Both rails of the isolated supply need to be connected to some point in the sensed circuit.

If an isolated 5V supply is not required this board may be used with input resistors up to 22k for 48V input.

TLP180GB (high CTR) optos reliably trigger with a LED current of 1mA. With the default 1K ohm input current-limiting resistors the inputs reliably trigger at 1.5V with either polarity inputs, compatible with 3.3 – 5V CMOS logic levels. Above 5V, the series resistance should be increased (either by changing the on-board resistors or by adding eternal series resistors) to ensure the opto’s input current remains in the range 1-20mA.

Input | Trigger voltage | Recommended input resistor (R3+ external) for 4-5 mA operating current
3.3V or 5V CMOS logic | 1.5V | 1k
| 3.3V – 5V | 2.2k
12V | | 3.3k
24V | | 6.8k
48V | | 12k


IDC Header

Digital Input Board (non-isolated)
The digital input board has eight diode-protected inputs and a direct GPIO connector mappable to GPIO 14/15.

It comes with two connector options – individual 3.81mm pluggable terminals or a 12-pin IDC header with the same pinouts as the analogue input board.


With the standard 1k ohm current-limiting resistors on the inputs, the inputs reliably trigger at 2V, and are compatible with 3.3V or greater logic levels. While the inputs are current limited and over-voltage protected, potentials of more than 48V difference from the board’s ground should be avoided.

If reduced current inputs are required, the input resistors may be raised to 47k or greater, as the bus expander has CMOS inputs draw less than 100uA and trigger at 1V and 2.7V (0.3 and 0.8 Vcc).


A representative direct digital input.

IDC Header


The IDC connector pin-out is compatible with the analogue input board

### Digital Output Board (Isolated)

The PCA9554 (or PCA9554A) is used for the digital output boards.

It is recommended that the ESPHome GPIO Switch platform is used instead of the bare GPIO Output.

https://esphome.io/components/switch/gpio

Eight digital outputs are provided, four as SPDT relay contacts and four as opto-coupler OC outputs.

The SPDT relays are Omron G5V-2_H1 (low current coil) equivalents, rated at 24V DC @ 1A or 0.5A @125V AC.

The open collector opto-coupler outputs are active low, and require current limiting resistors which should limit the sunk current to less than 20mA. The maximum VCE0 is 35V.

Voltages of more than 48V above or below the board’s ground plane should not be applied to any terminal.

Outputs are presented as 2-pin x 3.81mm pluggable terminal blocks.


A pin header is also provided to directly drive more substantial relays or SSRs, from outputs 0 to 3. No driver transistor is used, so drive currents should be limited to 5mA. 5V power is available at pins 1, 2, 11 & 12.


Connector: 2x6 x 0.1” pin header

## Specifications

Item | Specification

All boards
Connectors Digital, analogue & 5V power | 3.81 mm pluggable terminals Two and three pin Kefa KF2EDG, Amphenol TJ, etc. 12 and 14-pin IDC sockets
RVR equipment | DB-15F (2-row)

Main
Power supply | Micro USB or 3.81mm pluggable header 5V 50mA + daughter boards
Pico 3.3V supply | Supply: 250mA max (all boards) Use Extender Board for greater current.
Peak-detecting analogue inputs | FSD: 400mV(p-p) or greater Linearity 1% of FSD or better Rise time: 20mS Fall time: 2Sec
PWM output | Range: 0-100% Output: 4.5V @ 100% Ripple: 7mV p-p Linearity; < 7mV deviation (3.3V output)
Expansion connectors | I2C_0 QWIIC and header pins 30 pin Expansion header

Analogue Input (pluggable terminal or IDC)
Number | A maximum of four analogue boards in a stack
Purpose | General purpose analogue inputs.
Connectors | Eight 2-pin pluggable connectors Or 12-pin IDC connector.
Inputs | A0-A7 3.5V (p-p) FSD or greater. Max 50V p-p. 10k ohms or greater. Transient suppression capacitor Input level controls 10-bit resolution, < 0.5 bit INL/DNL
Expansion | I2C_0 QWIIC and pin header I2C_1 QWIIC and pin header
Power supply | 5V < 10mA (3.3V reference) ADC 3.3V supply LM4041 regulator (<1mA) from 5V rail

Analogue Input (RVR)
Number | A maximum of four analogue boards in a stack
Purpose | Optimised for RVR RF equipment (TEX-150 transmitter or RXRL STL)
ADC Sensitivity Linearity | ADC 3.3V FSD 10-bit resolution, < 0.5 bit INL/DNL
Analogue Inputs | A0-A1 Peak detector. See main board specification. A2-A7 3.9V FSD with specified gain resistors 6.8k ohms, 250 Hz LPF A2 Pullup resistor (3.3V) for OC input. A6 Additional patch point near A0/A1
Expansion | I2C_0 QWIIC and pin header I2C_1 QWIIC and pin header
Power supply | 5V < 10mA ADC 3.3V supply LM4041 regulator (<1mA) from 5V rail

Digital Input and Output Boards
Number | A maximum of four Digital Input + Output boards in a stack Eight if a mix of PCA9554 and PCA9554A ICs are used.

Digital Input – Isolated (pluggable terminal or IDC)
Connectors | Eight 2-pin 3.81mm pluggable connectors or 16-pin IDC connector.
Digital inputs | Opto-isolated (PC-817) Trigger: 1-20mA 3.3V - 12V compatible with specified (2.2k) input resistors.
Expansion | I2C_0 QWIIC and pin header I2C_1 QWIIC and pin header
Power supply | 3.3V < 10mA

Digital Input – Non-isolated (pluggable terminal or IDC)
Connectors | Eight 2-pin 3.81mm pluggable connectors or 14-pin IDC connector (includes 5V and 3.3V power)
Digital inputs | 3.3V - 12V input (optional 10k pull-up resistors).
Expansion | I2C_0 QWIIC and pin header I2C_1 QWIIC and pin header
Power supply | 3.3V < 10mA

Digital Output
Relay outputs | SPDT Omron G5V-2_H1 (low power coil) 24v @ 1A
Expansion | I2C_0 QWIIC and pin header I2C_1 QWIIC and pin header
Power supply | 5V < 150mA (all outputs active) 3.3V < 5mA

Extender Board
Power | Alternate 5V input Alternate 3.3V (500mA) supply for EXPAND_B connector.
Expansion | I2C_0 QWIIC and pin header I2C_1 QWIIC and pin header

## Tested I2C Devices

While any SPI or I2C-based sensors and control devices supported by ESPHome may be used, the design has been successfully tested with the following devices.

### Temperature and Humidity Sensor (SHT40)

- The standard configuration is a SHT40 on I2C_0.
- A different ESPHome-compatible sensor, such as the BME680, could be used for a second sensor.
- Alternately, a second SHT40 could be connected on I2C_1.

### BME680 Temperature, Humidity, Barometric Pressure and Gas Sensor

- Temperature, Humidity, Barometric Pressure and Gas Sensor
- Will detect Volatile Organic Compound (VOC) gases such as ethanol, acetone or ethane at moderate concentrations.

### VEML7700 Ambient Light Sensor

- I2C

https://esphome.io/components/sensor/veml7700/

### AM312 PIR Motion Sensor

- GPIO

https://omarghader.github.io/esp32-am312-pir-motion-sensor/

# AM312 connected to a GPIO pin and +5V binary_sensor:

- platform: gpio
pin: 15 # Pin may be changed name: "PIR Sensor"
device_class: motion

### WiFi Webcams

Several ONVIF-compatible webcams were tested (with and without PTZ controls).

Some worked and some didn’t!

https://www.home-assistant.io/integrations/onvif/

## Troubleshooting

The HomeAssistant community forum is a useful place to search for problem resolutions on both platforms.

https://community.home-assistant.io/

The documentation is regularly updated for both platforms:

https://www.home-assistant.io/

https://esphome.io/

ESPHome
Symptom | Cause | Resolution
SPI bus function behaving erratically | Two devices sharing a CS pin | Board jumpers or CS pin definitions.
| SPI bus too long | SPI devices on same stack as CPU board. Slow the SPI data rate.
Poor WiFi coverage | Shielding from boards or enclosure | CPU board to top of stack. Use a plastic enclosure.
Device not appearing in HA Devices or Dashboards after compile and install. | Not enabled | Enable ESPHome device in Settings > Devices > HACS

Home Assistant
Issue | Likely cause | Solution
Dashboard does not update after changing device config or restarting device. | 60 second delay for HA to update entities list. | Reload dashboard page in browser.
New ESPHome device not showing on dashboard or devices list. | Not enabled | Enable ESPHome device Settings > Devices > HACS
New entity not showing on dashboard after refresh. | Not enabled. | Enable on Entities screen menu
Digital input not reading reliably. | Opto current too low. | Reduce input resistance or increase voltage.
Analog peak not reading reliably. | Peak decays before reading. | Add config software filter to read more often and calculate max value over time. Increase C in peak detector circuit. 100uF is a practical maximum.
PWM not linear. | Gamma is set to default (2.8). | Set gamma_correct to 1.0

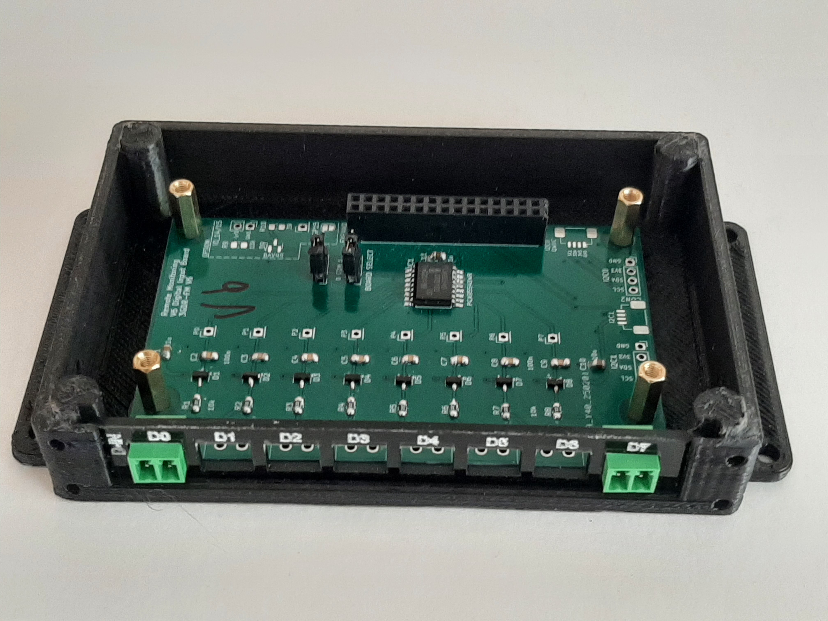
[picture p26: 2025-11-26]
Gallery/one board in base.jpg

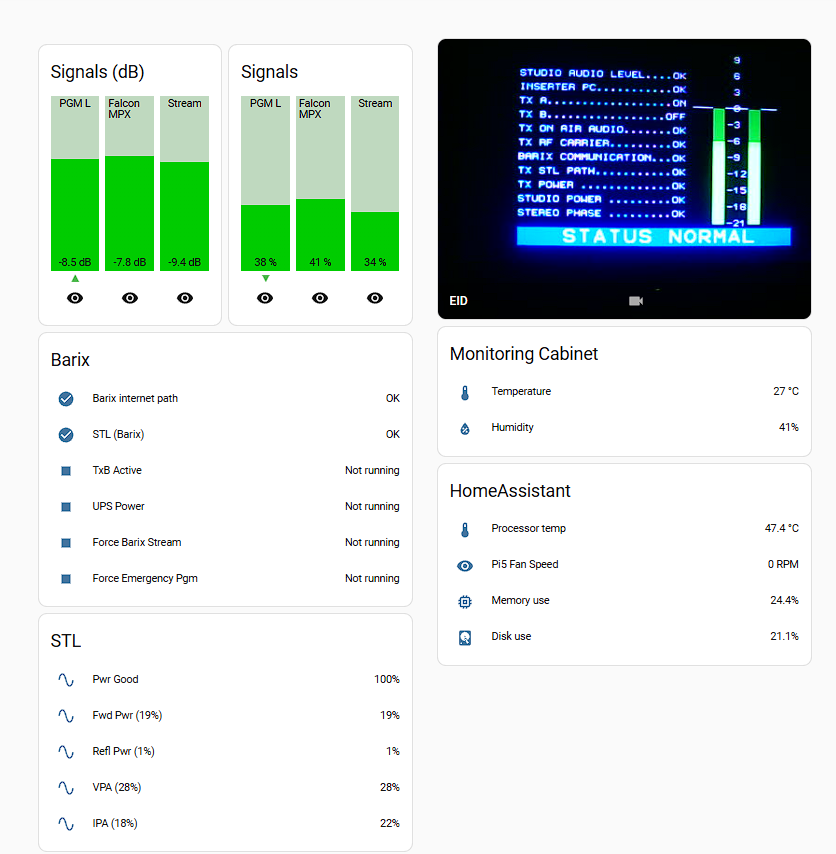
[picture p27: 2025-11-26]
Gallery/Control room remote dashboard.png

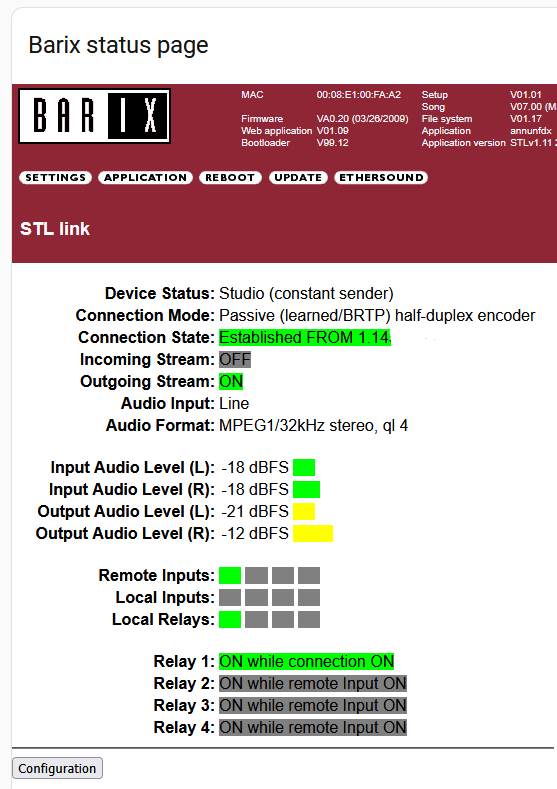
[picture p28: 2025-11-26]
Gallery/Barix Exstreamer STL remote configuration.png

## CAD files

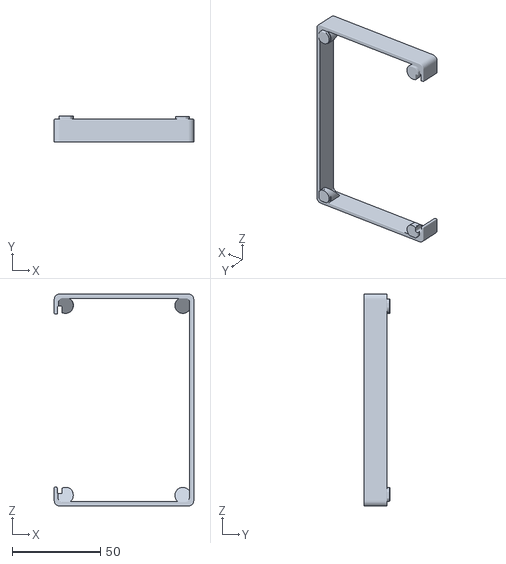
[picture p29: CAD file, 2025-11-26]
Case/middle.stl
79.0 x 14.8 x 120.0

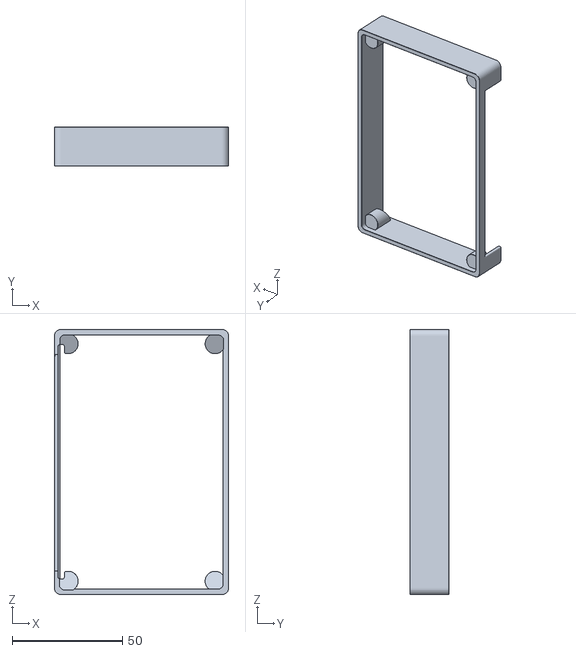
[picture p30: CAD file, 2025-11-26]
Case/top.stl
79.0 x 17.8 x 120.0

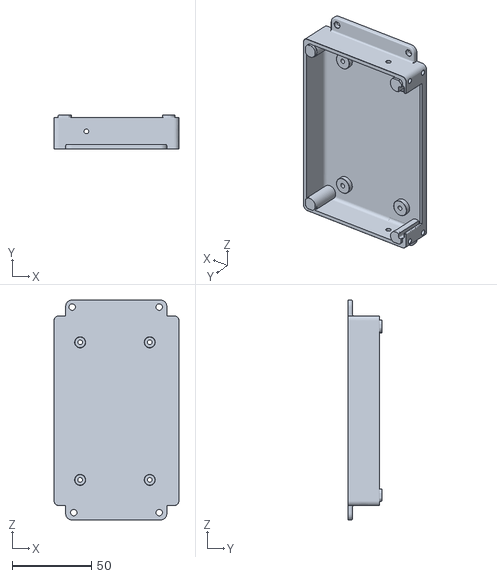
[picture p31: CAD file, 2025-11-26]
Case/base.stl
79.0 x 21.6 x 139.1

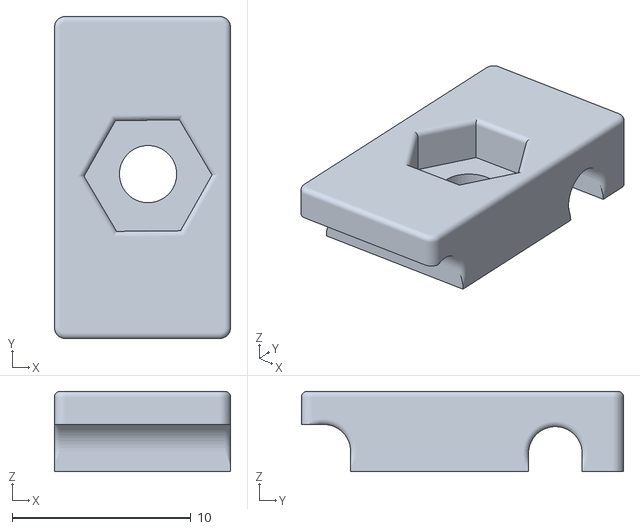
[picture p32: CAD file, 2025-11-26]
Case/bar holder.stl
9.84 x 18.0 x 4.48

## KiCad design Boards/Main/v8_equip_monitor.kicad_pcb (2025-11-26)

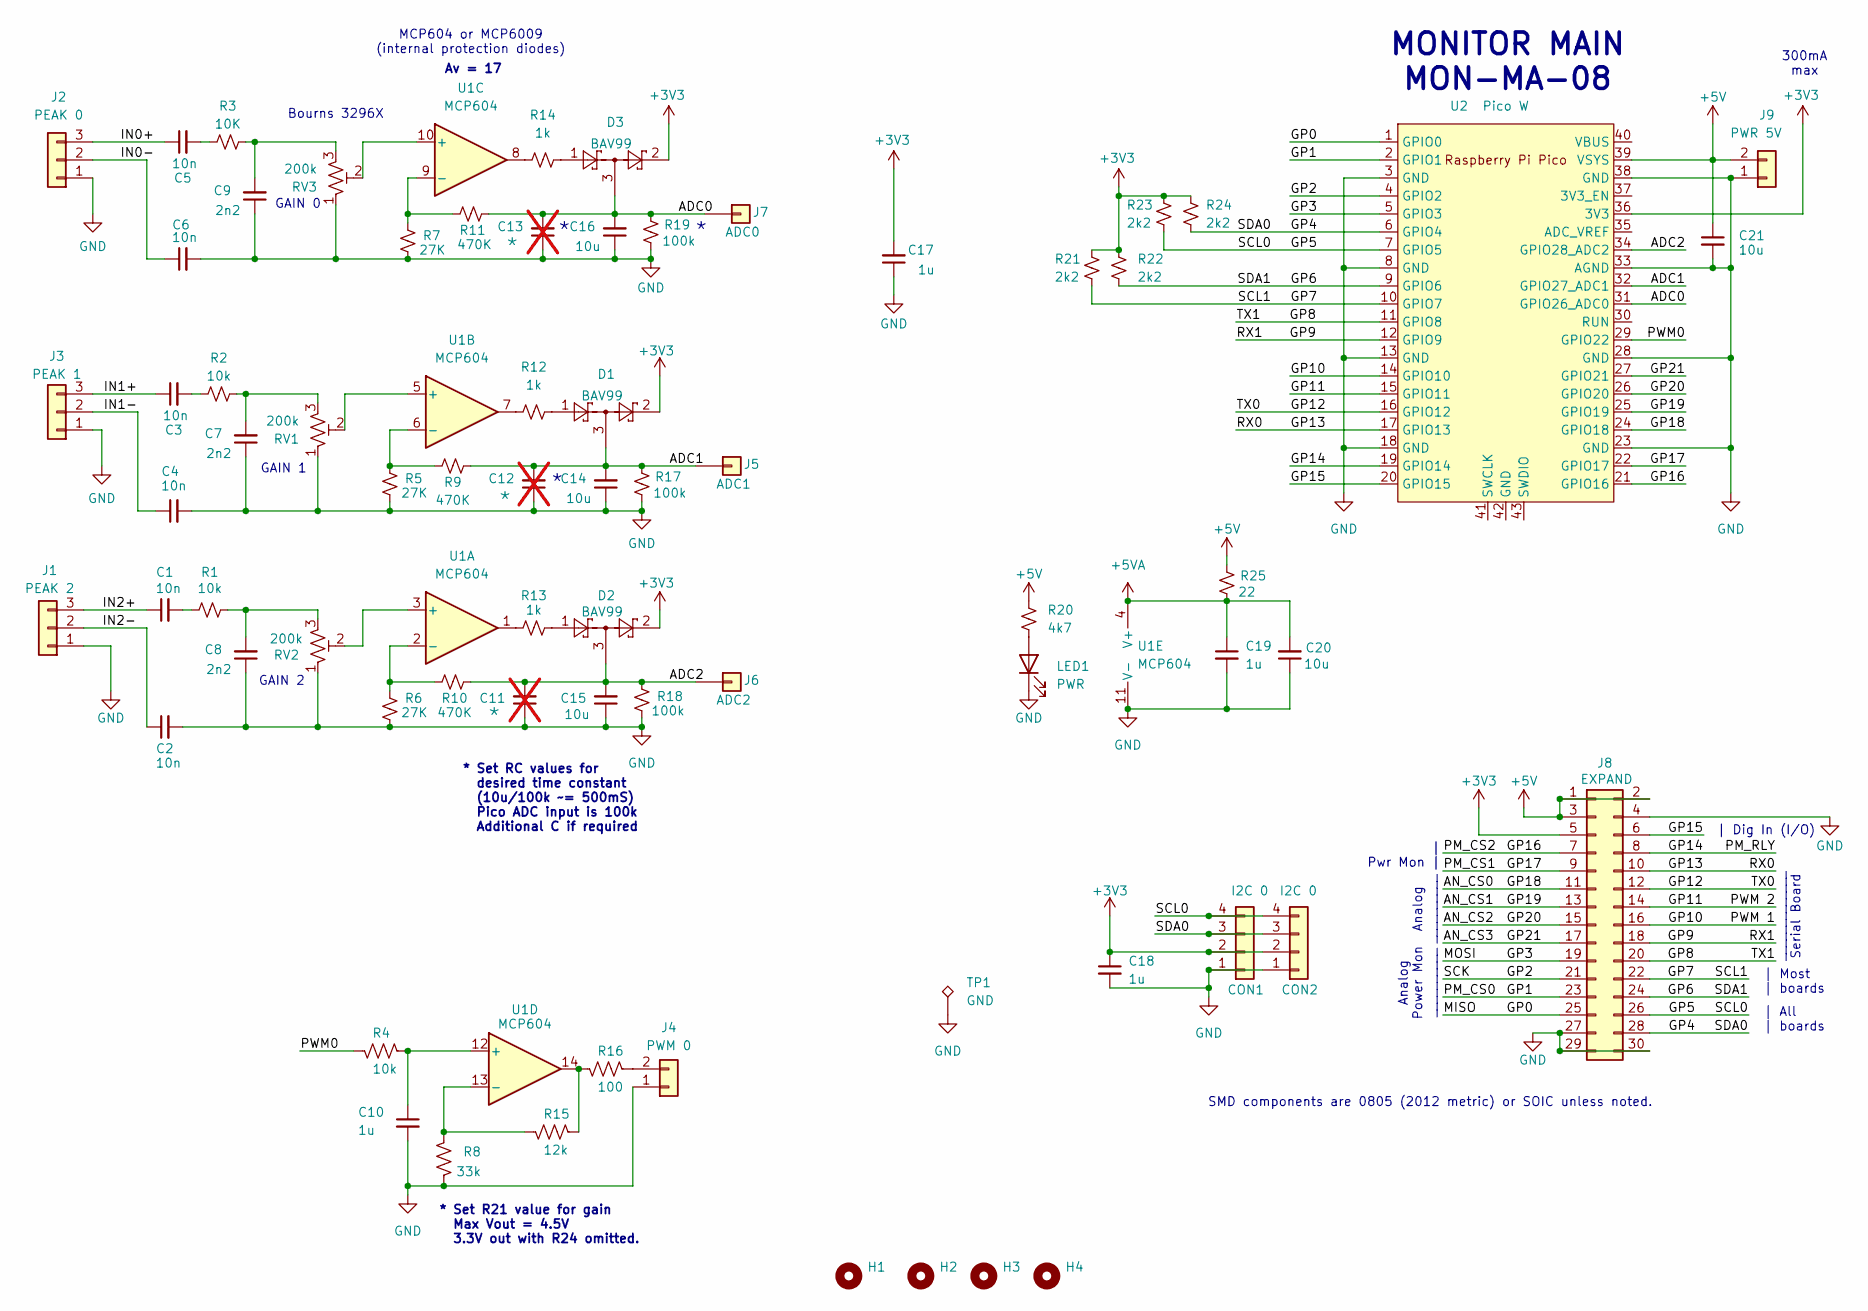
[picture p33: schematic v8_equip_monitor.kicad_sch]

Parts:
C1, C2, C3, C4, C5, C6: 10n; C_0805_2012Metric_Pad1.18x1.45mm_HandSolder
C7, C8, C9: 2n2; C_0805_2012Metric_Pad1.18x1.45mm_HandSolder
C10, C17, C18, C19: 1u; C_0805_2012Metric_Pad1.18x1.45mm_HandSolder
C11, C12, C13: *; C_0805_2012Metric_Pad1.18x1.45mm_HandSolder; not fitted
C14, C15, C16, C20, C21: 10u; C_0805_2012Metric_Pad1.18x1.45mm_HandSolder
CON1: I2C 0; PinSocket_1x04_P2.54mm_Vertical
CON2: I2C 0; JST_SH_SM04B-SRSS-TB_1x04-1MP_P1.00mm_Horizontal_wide_MP
D1, D2, D3: BAV99; SOT-23
H1, H2, H3, H4: MountingHole; MountingHole_3.5mm_no_fill
J1: PEAK 2; K3EDG; Mouser Part Number 649-220110-D031A01LF
J2: PEAK 0; K3EDG; Mouser Part Number 649-220110-D031A01LF
J3: PEAK 1; K3EDG; Mouser Part Number 649-220110-D031A01LF
J4: PWM 0; K2EDG; Mouser Part Number 649-220110-D021A01LF
J5: ADC1; PinHeader_1x01_P2.54mm_Vertical
J6: ADC2; PinHeader_1x01_P2.54mm_Vertical
J7: ADC0; PinHeader_1x01_P2.54mm_Vertical
J8: EXPAND; PinHeader_2x15_P2.54mm_Vertical
J9: PWR 5V; K2EDG
LED1: PWR; LED_0805_2012Metric_Pad1.15x1.40mm_HandSolder
R1, R2, R4: 10k; R_0805_2012Metric_Pad1.20x1.40mm_HandSolder
R3: 10K; R_0805_2012Metric_Pad1.20x1.40mm_HandSolder
R5, R6, R7: 27K; R_0805_2012Metric_Pad1.20x1.40mm_HandSolder
R8: 33k; R_0805_2012Metric_Pad1.20x1.40mm_HandSolder
R9, R10, R11: 470K; R_0805_2012Metric_Pad1.20x1.40mm_HandSolder
R12, R13, R14: 1k; R_0805_2012Metric_Pad1.20x1.40mm_HandSolder
R15: 12k; R_0805_2012Metric_Pad1.20x1.40mm_HandSolder
R16: 100; R_0805_2012Metric_Pad1.20x1.40mm_HandSolder
R17, R18, R19: 100k; R_0805_2012Metric_Pad1.20x1.40mm_HandSolder
R20: 4k7; R_0805_2012Metric_Pad1.20x1.40mm_HandSolder
R21, R22, R23, R24: 2k2; R_0805_2012Metric_Pad1.20x1.40mm_HandSolder
R25: 22; R_Axial_DIN0207_L6.3mm_D2.5mm_P10.16mm_Horizontal
RV1, RV2, RV3: 200k; Potentiometer_Bourns_3296X_Horizontal
TP1: GND; TestPoint_THTPad_2.0x2.0mm_Drill1.0mm
U1: MCP604; SOIC-14_3.9x8.7mm_P1.27mm
U2: Pico W; RPi_Pico_THT_BASIC_INSIDE

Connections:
+3V3: C17.2, C18.1, CON1.2, CON2.2, D1.2, D2.2, D3.2, J8.5, R21.1, R22.1, R23.1, R24.1, U2.36 (3V3)
+5V: C21.1, J8.1, J8.2, J8.3, J9.2, R20.1, R25.2, U2.39 (VSYS)
+5VA: C19.1, C20.2, R25.1, U1.4 (V+)
/ADC0: C13.2, C16.2, D3.3, J7.1, R11.2, R19.2, U2.31 (GPIO26_ADC0)
/ADC1: C12.2, C14.2, D1.3, J5.1, R9.2, R17.2, U2.32 (GPIO27_ADC1)
/ADC2: C11.2, C15.2, D2.3, J6.1, R10.2, R18.2, U2.34 (GPIO28_ADC2)
/AN_CS0: J8.11, U2.24 (GPIO18)
/AN_CS1: J8.13, U2.25 (GPIO19)
/AN_CS2: J8.15, U2.26 (GPIO20)
/AN_CS3: J8.17, U2.27 (GPIO21)
/GP0: J8.25, U2.1 (GPIO0)
/GP1: J8.23, U2.2 (GPIO1)
/GP2: J8.21, U2.4 (GPIO2)
/GP3: J8.19, U2.5 (GPIO3)
/GP4: CON1.3, CON2.3, J8.28, R24.2, U2.6 (GPIO4)
/GP5: CON1.4, CON2.4, J8.26, R23.2, U2.7 (GPIO5)
/GP6: J8.24, R22.2, U2.9 (GPIO6)
/GP7: J8.22, R21.2, U2.10 (GPIO7)
/GP8: J8.20, U2.11 (GPIO8)
/GP9: J8.18, U2.12 (GPIO9)
/GP10: J8.16, U2.14 (GPIO10)
/GP11: J8.14, U2.15 (GPIO11)
/GP12: J8.12, U2.16 (GPIO12)
/GP13: J8.10, U2.17 (GPIO13)
/GP14: J8.8, U2.19 (GPIO14)
/GP15: J8.6, U2.20 (GPIO15)
/GP16: J8.7, U2.21 (GPIO16)
/GP17: J8.9, U2.22 (GPIO17)
/IN0+: C5.1, J2.3
/IN0-: C6.1, J2.2
/IN1+: C3.1, J3.3
/IN1-: C4.1, J3.2
/IN2+: C1.1, J1.3
/IN2-: C2.1, J1.2
/PWM0: R4.1, U2.29 (GPIO22)
GND: C2.2, C4.2, C6.2, C7.1, C8.1, C9.1, C10.2, C11.1, C12.1, C13.1, C14.1, C15.1, C16.1, C17.1, C18.2, C19.2, C20.1, C21.2, CON1.1, CON2.1, J1.1, J2.1, J3.1, J4.1, J8.4, J8.27, J8.29, J8.30, J9.1, LED1.1 (K), R5.1, R6.1, R7.1, R8.1, R17.1, R18.1, R19.1, RV1.1, RV2.1, RV3.1, TP1.1, U1.11 (V-), U2.3 (GND), U2.8 (GND), U2.13 (GND), U2.18 (GND), U2.23 (GND), U2.28 (GND), U2.33 (AGND), U2.38 (GND)
unnamed: C1.2, R1.1
unnamed: C3.2, R2.1
unnamed: C5.2, R3.1
unnamed: C7.2, R2.2, RV1.3
unnamed: C8.2, R1.2, RV2.3
unnamed: C9.2, R3.2, RV3.3
unnamed: D1.1, R12.2
unnamed: D2.1, R13.2
unnamed: D3.1, R14.2
unnamed: J4.2, R16.2
unnamed: LED1.2 (A), R20.2
unnamed: R12.1, U1.7
unnamed: R13.1, U1.1
unnamed: R14.1, U1.8
unnamed: R15.2, R16.1, U1.14
unnamed: RV2.2, U1.3 (+)
unnamed: R6.2, R10.1, U1.2 (-)
unnamed: RV1.2, U1.5 (+)
unnamed: R5.2, R9.1, U1.6 (-)
unnamed: RV3.2, U1.10 (+)
unnamed: R7.2, R11.1, U1.9 (-)
unnamed: C10.1, R4.2, U1.12 (+)
unnamed: R8.2, R15.1, U1.13 (-)

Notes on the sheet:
Bourns 3296X
300mA max
| Pwr Mon |
| Dig In (I/O)
Analog Power Mon __________
* Set R21 value for gain Max Vout = 4.5V 3.3V out with R24 omitted.
GAIN 1
GAIN 2
MONITOR MAIN MON-MA-08
GAIN 0
Av = 17
| Most | boards
Analog __________
_____________ Serial Board
* Set RC values for desired time constant (10u/100k ~= 500mS) Pico ADC input is 100k Additional C if required
MCP604 or MCP6009 (internal protection diodes)
| All | boards
SMD components are 0805 (2012 metric) or SOIC unless noted.

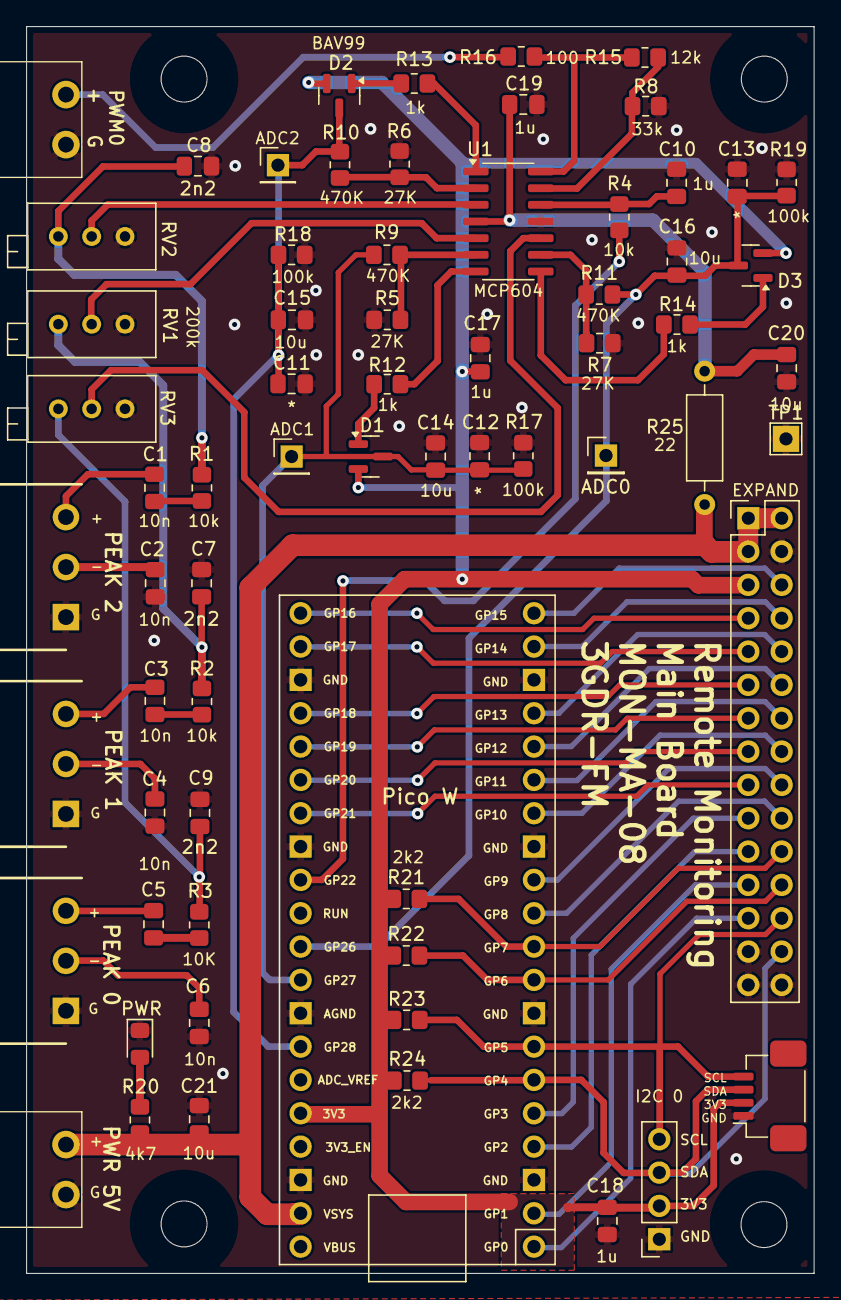
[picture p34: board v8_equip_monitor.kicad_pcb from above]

Board: 2 copper layers, 60.0 x 95.0 mm, 71 parts (0 on the bottom side), 59 nets.

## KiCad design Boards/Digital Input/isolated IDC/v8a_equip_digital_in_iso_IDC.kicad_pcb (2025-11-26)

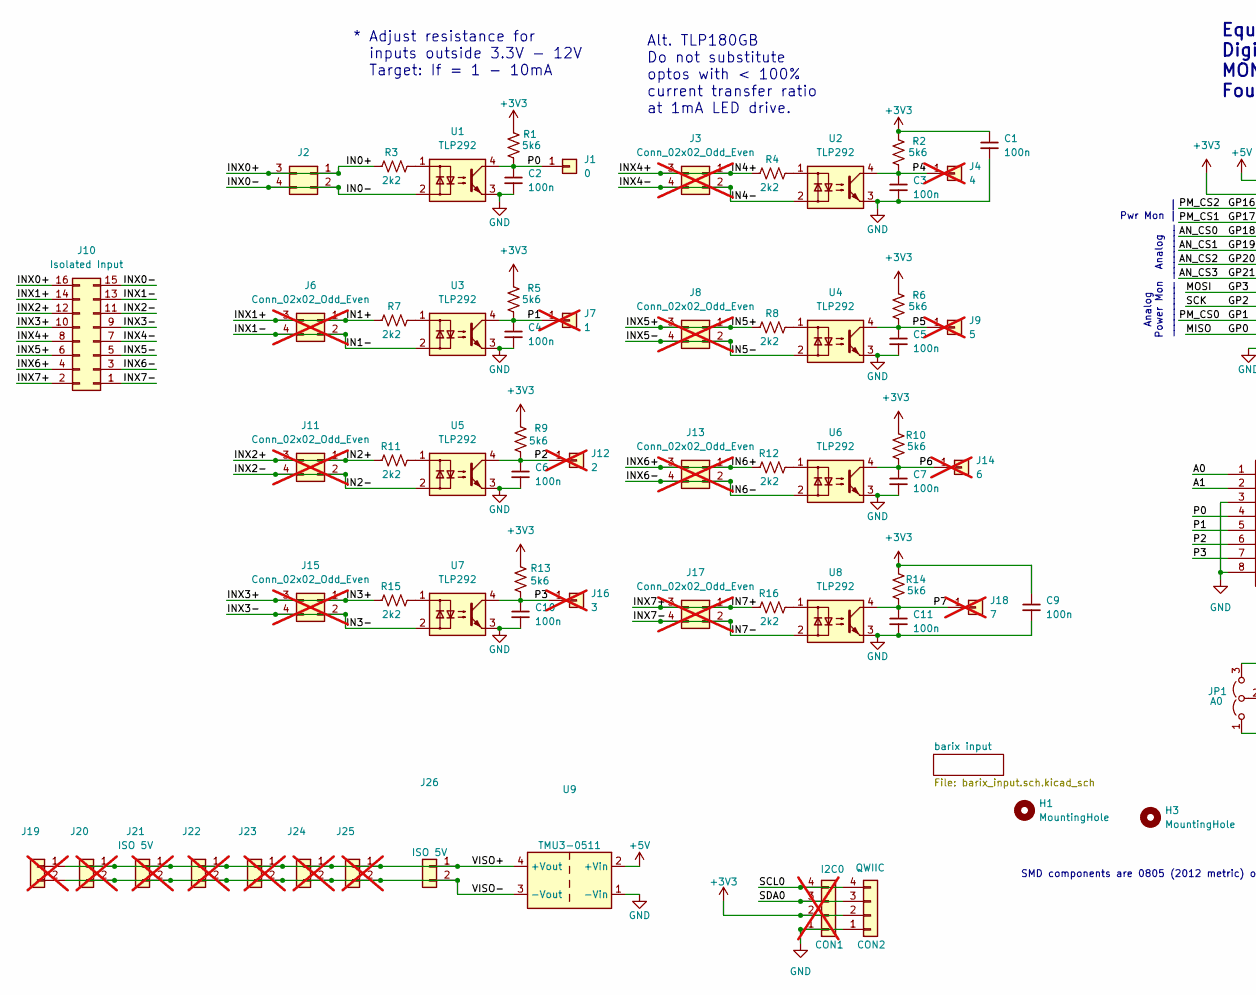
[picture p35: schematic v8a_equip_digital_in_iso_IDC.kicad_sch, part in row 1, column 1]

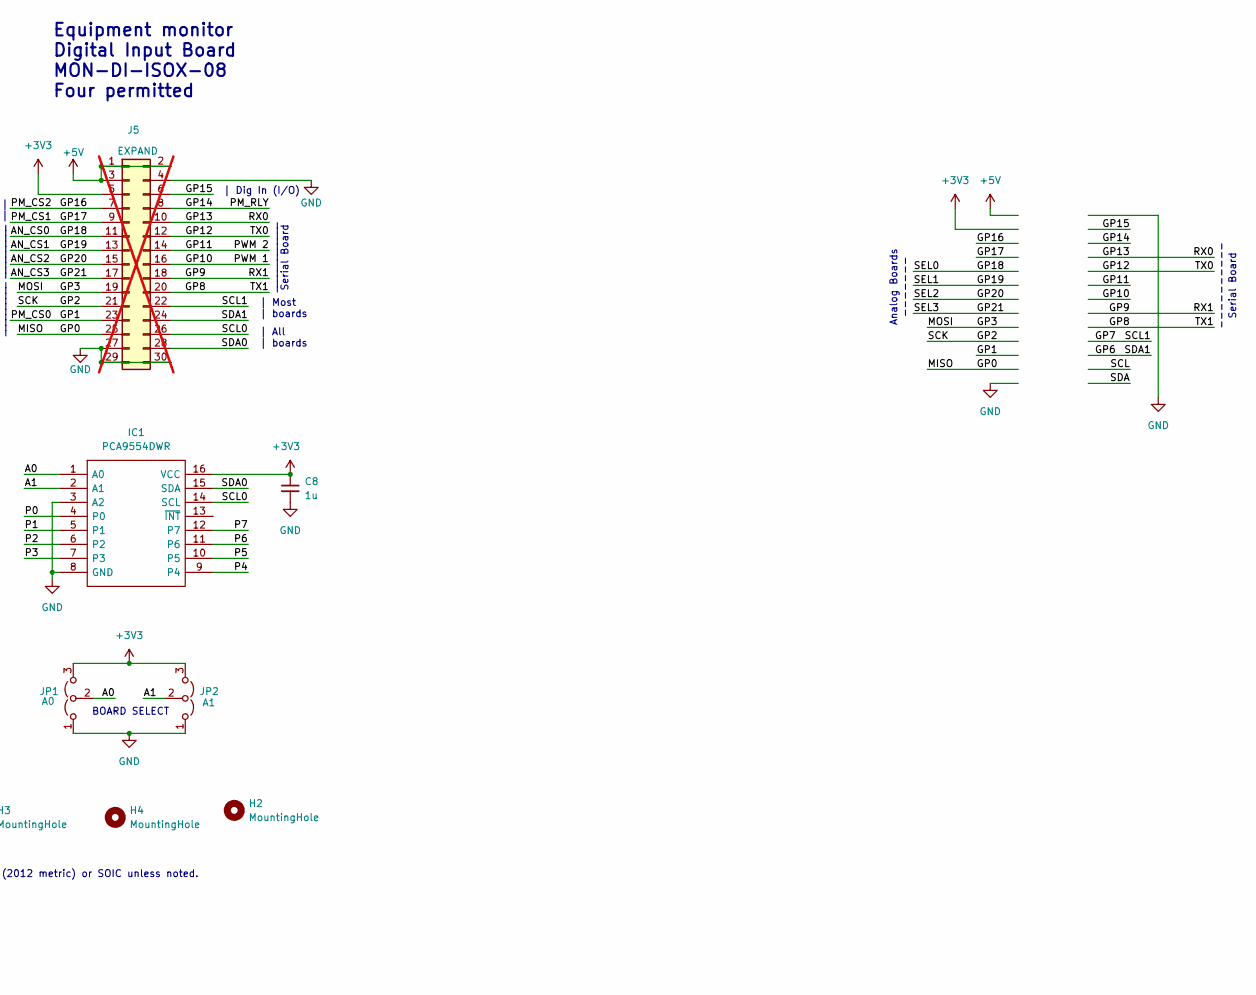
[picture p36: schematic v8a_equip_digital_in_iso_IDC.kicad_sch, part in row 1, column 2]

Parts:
C1, C2, C3, C4, C5, C6, C7, C9, C10, C11: 100n; C_0805_2012Metric_Pad1.18x1.45mm_HandSolder
C8: 1u; C_0805_2012Metric_Pad1.18x1.45mm_HandSolder
CON1: I2C0; PinSocket_1x04_P2.54mm_Vertical; not fitted
CON2: QWIIC; JST_SH_SM04B-SRSS-TB_1x04-1MP_P1.00mm_Horizontal_wide_MP
H1, H2, H3, H4: MountingHole; MountingHole_3.5mm_no_fill
IC1: PCA9554DWR; SOIC127P1030X265-16N; Mouser Part Number 595-PCA9534DWR
J1: 0; PinHeader_1x01_P2.54mm_Vertical
J2: Conn_02x02_Odd_Even; PinHeader_2x02_P1.27mm_Vertical
J3, J6, J8, J11, J13, J15, J17: Conn_02x02_Odd_Even; PinHeader_2x02_P1.27mm_Vertical; not fitted
J4: 4; PinHeader_1x01_P2.54mm_Vertical; not fitted
J5: EXPAND; PinHeader_2x15_P2.54mm_Vertical; not fitted
J7: 1; PinHeader_1x01_P2.54mm_Vertical; not fitted
J9: 5; PinHeader_1x01_P2.54mm_Vertical; not fitted
J10: Isolated Input; SHDRRA16W63P254_2X8_2290X1740X700P; Mouser Part Number 538-90130-3112
J12: 2; PinHeader_1x01_P2.54mm_Vertical; not fitted
J14: 6; PinHeader_1x01_P2.54mm_Vertical; not fitted
J16: 3; PinHeader_1x01_P2.54mm_Vertical; not fitted
J18: 7; PinHeader_1x01_P2.54mm_Vertical; not fitted
J19, J20, J22, J23, J24, J25: Conn_02x02_Odd_Even; PinHeader_1x02_P1.27mm_Vertical; not fitted
J21: ISO 5V; PinHeader_1x02_P1.27mm_Vertical; not fitted
J26: ISO 5V; PinHeader_1x02_P1.27mm_Vertical
JP1: A0; PinHeader_1x03_P2.54mm_Vertical
JP2: A1; PinHeader_1x03_P2.54mm_Vertical
R1, R2, R5, R6, R9, R10, R13, R14: 5k6; R_0805_2012Metric_Pad1.20x1.40mm_HandSolder
R3, R4, R7, R8, R11, R12, R15, R16: 2k2; R_0805_2012Metric_Pad1.20x1.40mm_HandSolder
U1, U2, U3, U4, U5, U6, U7, U8: TLP292; TLP_OPTO_WIDE_PINS
U9: TMU3-0511; Converter_DCDC_TRACO_TMU3-05xx_12xx_THT

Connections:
+3V3: C1.1, C8.1, C9.1, CON1.2, CON2.2, IC1.16 (VCC), J5.5, JP1.3 (B), JP2.3 (B), R1.1, R2.1, R5.1, R6.1, R9.1, R10.1, R13.1, R14.1
+5V: J5.1, J5.2, J5.3, U9.2 (+Vin)
/A0: IC1.1 (A0), JP1.2 (C)
/A1: IC1.2 (A1), JP2.2 (C)
/AN_CS0: J5.11
/AN_CS1: J5.13
/AN_CS2: J5.15
/AN_CS3: J5.17
/GP0: J5.25
/GP1: J5.23
/GP2: J5.21
/GP3: J5.19
/GP6: J5.24
/GP7: J5.22
/GP8: J5.20
/GP9: J5.18
/GP10: J5.16
/GP11: J5.14
/GP12: J5.12
/GP13: J5.10
/GP14: J5.8
/GP15: J5.6
/GP16: J5.7
/GP17: J5.9
/IN0+: J2.1, J2.3, J10.16, R3.2
/IN0-: J2.2, J2.4, J10.15, U1.2
/IN1+: J6.1, J6.3, J10.14, R7.2
/IN1-: J6.2, J6.4, J10.13, U3.2
/IN2+: J10.12, J11.1, J11.3, R11.2
/IN2-: J10.11, J11.2, J11.4, U5.2
/IN3+: J10.10, J15.1, J15.3, R15.2
/IN3-: J10.9, J15.2, J15.4, U7.2
/IN4+: J3.1, J3.3, J10.8, R4.2
/IN4-: J3.2, J3.4, J10.7, U2.2
/IN5+: J8.1, J8.3, J10.6, R8.2
/IN5-: J8.2, J8.4, J10.5, U4.2
/IN6+: J10.4, J13.1, J13.3, R12.2
/IN6-: J10.3, J13.2, J13.4, U6.2
/IN7+: J10.2, J17.1, J17.3, R16.2
/IN7-: J10.1, J17.2, J17.4, U8.2
/P0: C2.1, IC1.4 (P0), J1.1, R1.2, U1.4
/P1: C4.1, IC1.5 (P1), J7.1, R5.2, U3.4
/P2: C6.1, IC1.6 (P2), J12.1, R9.2, U5.4
/P3: C10.1, IC1.7 (P3), J16.1, R13.2, U7.4
/P4: C3.1, IC1.9 (P4), J4.1, R2.2, U2.4
/P5: C5.1, IC1.10 (P5), J9.1, R6.2, U4.4
/P6: C7.1, IC1.11 (P6), J14.1, R10.2, U6.4
/P7: C11.1, IC1.12 (P7), J18.1, R14.2, U8.4
/SCL0: CON1.4, CON2.4, IC1.14 (SCL), J5.26
/SDA0: CON1.3, CON2.3, IC1.15 (SDA), J5.28
/VISO+: J19.1, J20.1, J21.1, J22.1, J23.1, J24.1, J25.1, J26.1, U9.4 (+Vout)
/VISO-: J19.2, J20.2, J21.2, J22.2, J23.2, J24.2, J25.2, J26.2, U9.3 (-Vout)
GND: C1.2, C2.2, C3.2, C4.2, C5.2, C6.2, C7.2, C8.2, C9.2, C10.2, C11.2, CON1.1, CON2.1, IC1.3 (A2), IC1.8 (GND), J5.4, J5.27, J5.29, J5.30, JP1.1 (A), JP2.1 (A), U1.3, U2.3, U3.3, U4.3, U5.3, U6.3, U7.3, U8.3, U9.1 (-Vin)
unnamed: R3.1, U1.1
unnamed: R4.1, U2.1
unnamed: R7.1, U3.1
unnamed: R8.1, U4.1
unnamed: R11.1, U5.1
unnamed: R12.1, U6.1
unnamed: R15.1, U7.1
unnamed: R16.1, U8.1

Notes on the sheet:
| Pwr Mon |
Analog __________
BOARD SELECT
SMD components are 0805 (2012 metric) or SOIC unless noted.
| Dig In (I/O)
_____________ Serial Board
---------- Serial Board
Equipment monitor Digital Input Board MON-DI-ISOX-08 Four permitted
Analog Power Mon __________
| All | boards
* Adjust resistance for inputs outside 3.3V - 12V Target: If = 1 - 10mA
| Most | boards
Alt. TLP180GB Do not substitute optos with < 100% current transfer ratio at 1mA LED drive.
Analog Boards -------

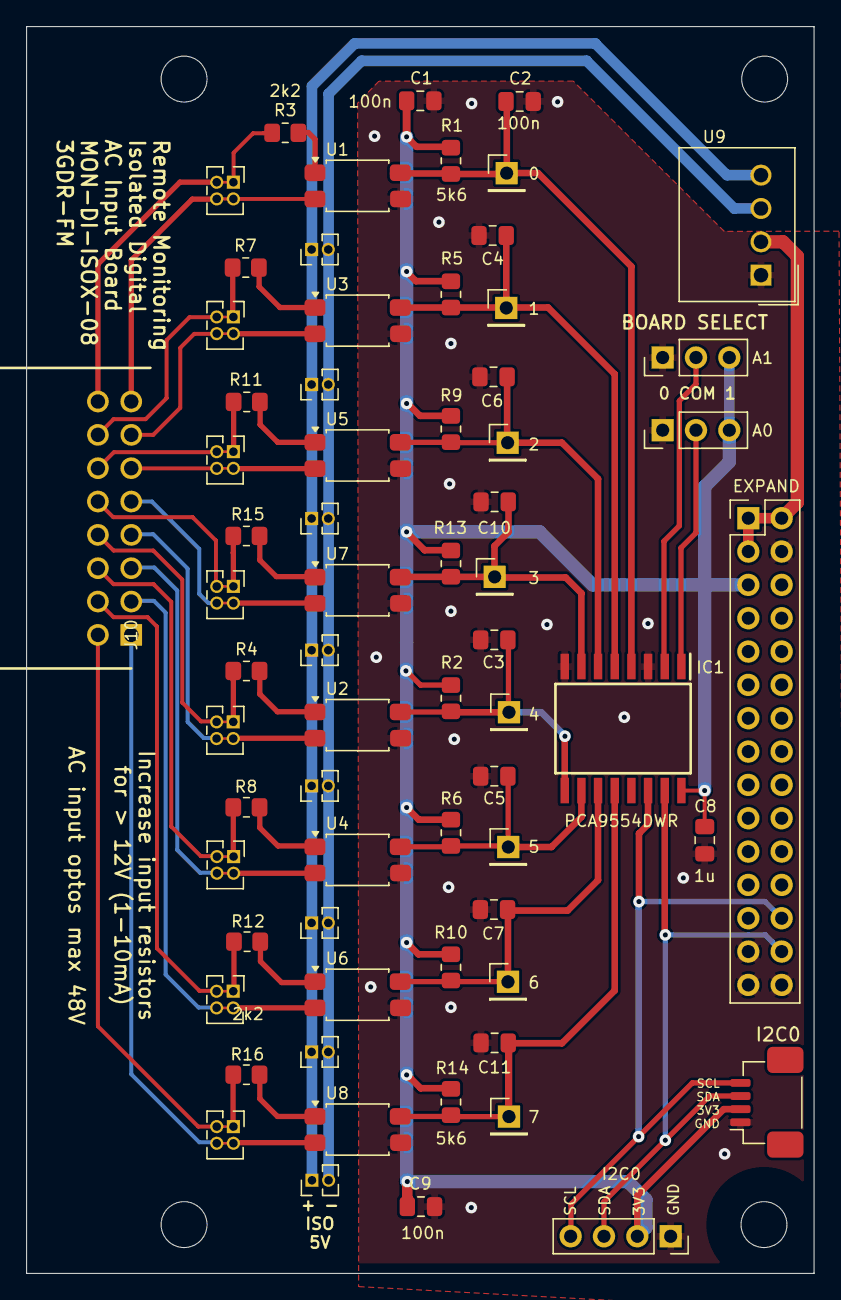
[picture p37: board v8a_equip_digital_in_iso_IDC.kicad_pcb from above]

Board: 2 copper layers, 60.0 x 95.0 mm, 71 parts (0 on the bottom side), 41 nets.

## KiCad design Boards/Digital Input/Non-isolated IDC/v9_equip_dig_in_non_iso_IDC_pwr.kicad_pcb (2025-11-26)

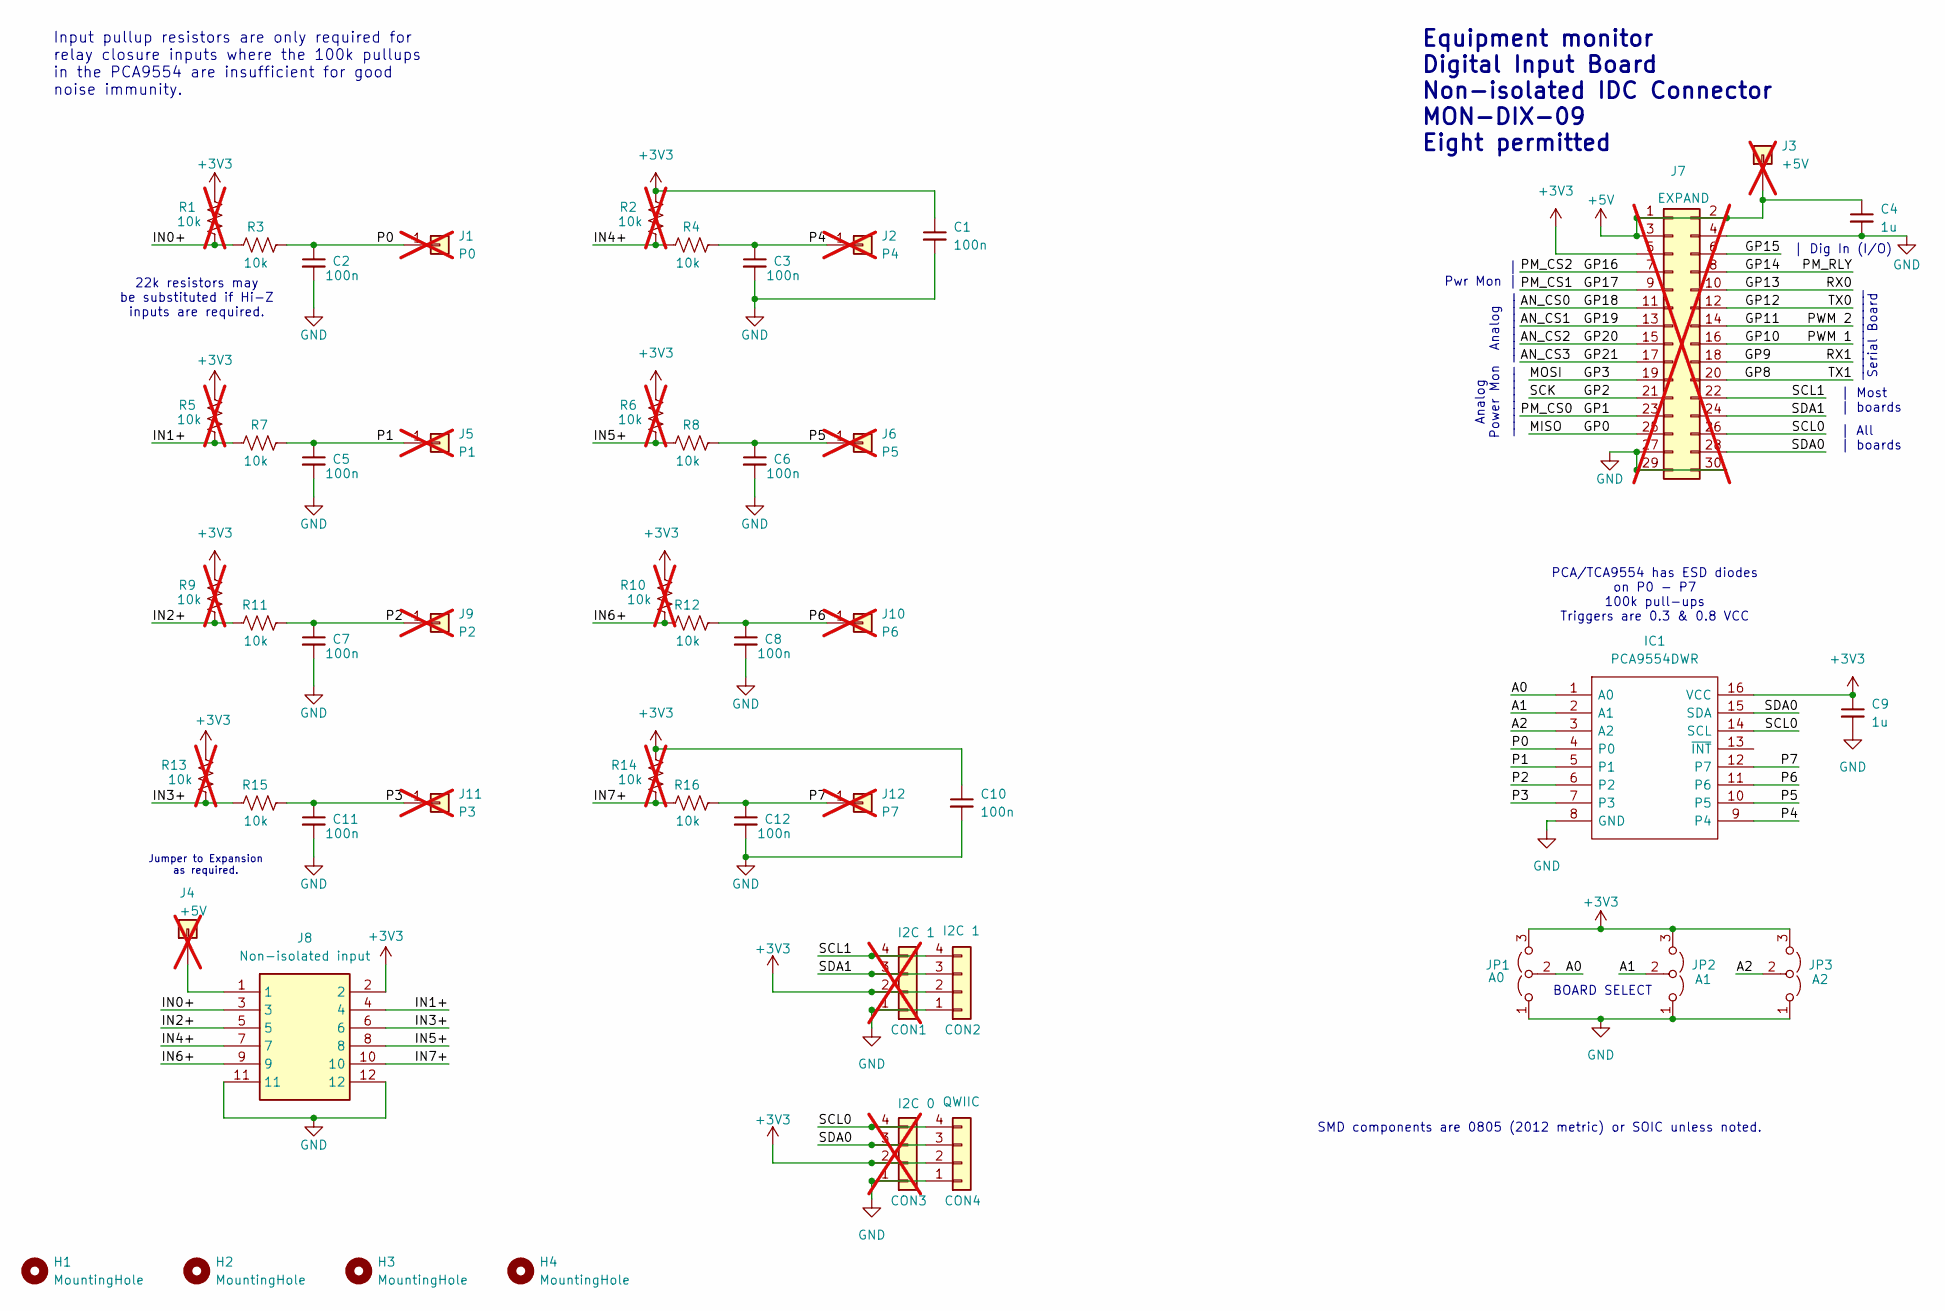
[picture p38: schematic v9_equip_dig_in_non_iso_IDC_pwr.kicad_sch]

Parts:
C1, C2, C3, C5, C6, C7, C8, C10, C11, C12: 100n; C_0805_2012Metric_Pad1.18x1.45mm_HandSolder
C4, C9: 1u; C_0805_2012Metric_Pad1.18x1.45mm_HandSolder
CON1: I2C 1; PinSocket_1x04_P2.54mm_Vertical; not fitted
CON2: I2C 1; JST_SH_SM04B-SRSS-TB_1x04-1MP_P1.00mm_Horizontal_wide_MP
CON3: I2C 0; PinSocket_1x04_P2.54mm_Vertical; not fitted
CON4: QWIIC; JST_SH_SM04B-SRSS-TB_1x04-1MP_P1.00mm_Horizontal_wide_MP
H1, H2, H3, H4: MountingHole; MountingHole_3.5mm_no_fill
IC1: PCA9554DWR; SOIC127P1030X265-16N; Mouser Part Number 595-PCA9534DWR
J1: P0; PinHeader_1x01_P2.54mm_Vertical; not fitted
J2: P4; PinHeader_1x01_P2.54mm_Vertical; not fitted
J3, J4: +5V; PinHeader_1x01_P2.54mm_Vertical; not fitted
J5: P1; PinHeader_1x01_P2.54mm_Vertical; not fitted
J6: P5; PinHeader_1x01_P2.54mm_Vertical; not fitted
J7: EXPAND; PinHeader_2x15_P2.54mm_Vertical; not fitted
J8: Non-isolated input; SHDRRA12W65P254_2X6_1758X1090X1005P; Mouser Part Number 538-90130-3112
J9: P2; PinHeader_1x01_P2.54mm_Vertical; not fitted
J10: P6; PinHeader_1x01_P2.54mm_Vertical; not fitted
J11: P3; PinHeader_1x01_P2.54mm_Vertical; not fitted
J12: P7; PinHeader_1x01_P2.54mm_Vertical; not fitted
JP1: A0; PinHeader_1x03_P2.54mm_Vertical
JP2: A1; PinHeader_1x03_P2.54mm_Vertical
JP3: A2; PinHeader_1x03_P2.54mm_Vertical
R1, R2, R5, R6, R9, R10, R13, R14: 10k; R_0805_2012Metric_Pad1.20x1.40mm_HandSolder; not fitted
R3, R4, R7, R8, R11, R12, R15, R16: 10k; R_0805_2012Metric_Pad1.20x1.40mm_HandSolder

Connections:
+3V3: C1.1, C9.1, C10.1, CON1.2, CON2.2, CON3.2, CON4.2, IC1.16 (VCC), J7.5, J8.2, JP1.3 (B), JP2.3 (B), JP3.3 (B), R1.1, R2.1, R5.1, R6.1, R9.1, R10.1, R13.1, R14.1
+5V: C4.1, J3.1, J7.1, J7.2, J7.3
/A0: IC1.1 (A0), JP1.2 (C)
/A1: IC1.2 (A1), JP2.2 (C)
/A2: IC1.3 (A2), JP3.2 (C)
/AN_CS0: J7.11
/AN_CS1: J7.13
/AN_CS2: J7.15
/AN_CS3: J7.17
/GP0: J7.25
/GP1: J7.23
/GP2: J7.21
/GP3: J7.19
/GP8: J7.20
/GP9: J7.18
/GP10: J7.16
/GP11: J7.14
/GP12: J7.12
/GP13: J7.10
/GP14: J7.8
/GP15: J7.6
/GP16: J7.7
/GP17: J7.9
/IN0+: J8.3, R1.2, R3.2
/IN1+: J8.4, R5.2, R7.2
/IN2+: J8.5, R9.2, R11.2
/IN3+: J8.6, R13.2, R15.2
/IN4+: J8.7, R2.2, R4.2
/IN5+: J8.8, R6.2, R8.2
/IN6+: J8.9, R10.2, R12.2
/IN7+: J8.10, R14.2, R16.2
/P0: C2.1, IC1.4 (P0), J1.1, R3.1
/P1: C5.1, IC1.5 (P1), J5.1, R7.1
/P2: C7.1, IC1.6 (P2), J9.1, R11.1
/P3: C11.1, IC1.7 (P3), J11.1, R15.1
/P4: C3.1, IC1.9 (P4), J2.1, R4.1
/P5: C6.1, IC1.10 (P5), J6.1, R8.1
/P6: C8.1, IC1.11 (P6), J10.1, R12.1
/P7: C12.1, IC1.12 (P7), J12.1, R16.1
/SCL0: CON3.4, CON4.4, IC1.14 (SCL), J7.26
/SCL1: CON1.4, CON2.4, J7.22
/SDA0: CON3.3, CON4.3, IC1.15 (SDA), J7.28
/SDA1: CON1.3, CON2.3, J7.24
GND: C1.2, C2.2, C3.2, C4.2, C5.2, C6.2, C7.2, C8.2, C9.2, C10.2, C11.2, C12.2, CON1.1, CON2.1, CON3.1, CON4.1, IC1.8 (GND), J7.4, J7.27, J7.29, J7.30, J8.11, J8.12, JP1.1 (A), JP2.1 (A), JP3.1 (A)
unnamed: J4.1, J8.1

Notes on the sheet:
PCA/TCA9554 has ESD diodes on P0 - P7 100k pull-ups Triggers are 0.3 & 0.8 VCC
| Pwr Mon |
Analog __________
22k resistors may be substituted if Hi-Z inputs are required.
BOARD SELECT
SMD components are 0805 (2012 metric) or SOIC unless noted.
| Dig In (I/O)
_____________ Serial Board
Equipment monitor Digital Input Board Non-isolated IDC Connector MON-DIX-09 Eight permitted
Analog Power Mon __________
| All | boards
Jumper to Expansion as required.
Input pullup resistors are only required for relay closure inputs where the 100k pullups in the PCA9554 are insufficient for good noise immunity.
| Most | boards

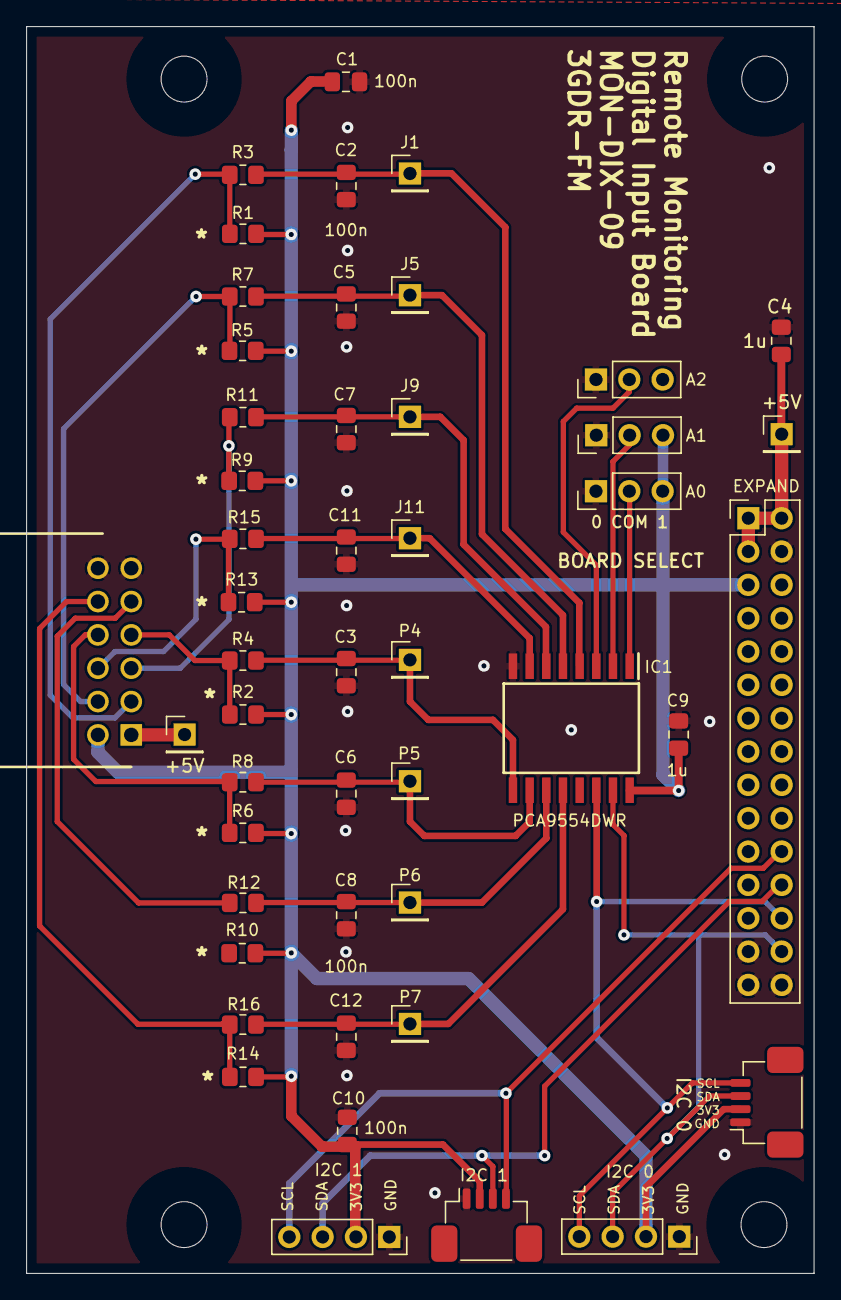
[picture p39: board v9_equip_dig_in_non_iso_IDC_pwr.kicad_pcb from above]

Board: 2 copper layers, 60.0 x 95.0 mm, 52 parts (0 on the bottom side), 27 nets.

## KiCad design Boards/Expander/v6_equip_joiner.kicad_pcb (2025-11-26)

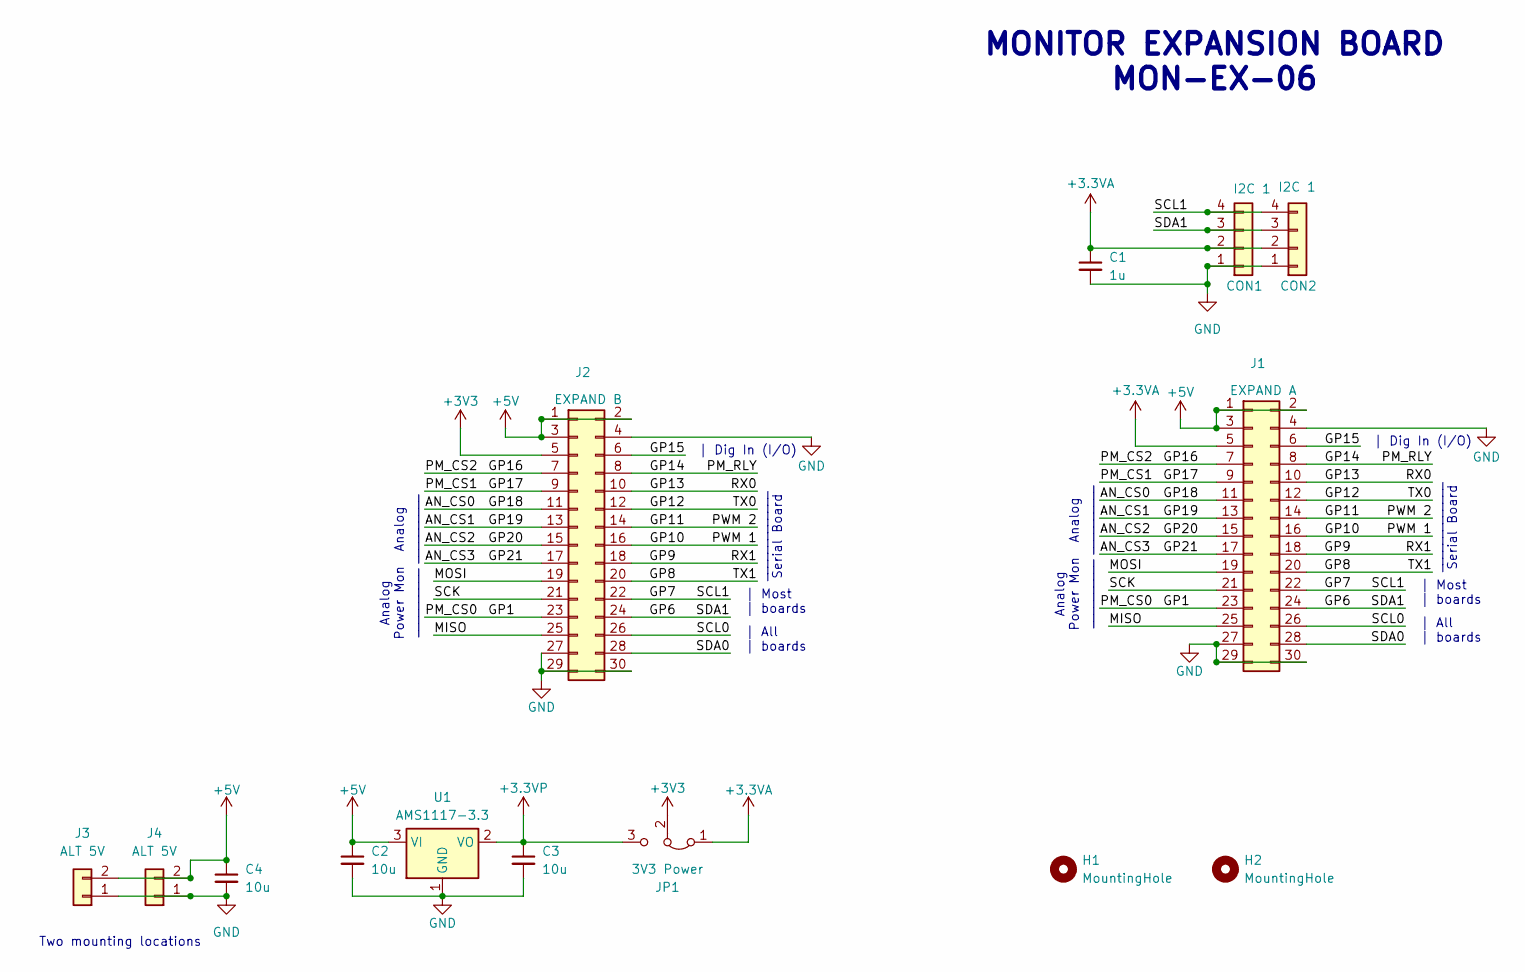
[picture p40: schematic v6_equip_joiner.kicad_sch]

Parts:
C1: 1u; C_0805_2012Metric_Pad1.18x1.45mm_HandSolder
C2, C3, C4: 10u; C_0805_2012Metric_Pad1.18x1.45mm_HandSolder
CON1: I2C 1; PinSocket_1x04_P2.54mm_Vertical
CON2: I2C 1; JST_SH_SM04B-SRSS-TB_1x04-1MP_P1.00mm_Horizontal_wide_MP
H1, H2: MountingHole; MountingHole_3.5mm
J1: EXPAND A; PinHeader_2x15_P2.54mm_Vertical
J2: EXPAND B; PinHeader_2x15_P2.54mm_Vertical
J3, J4: ALT 5V; OQ0232510000G
JP1: 3V3 Power; SolderJumper-3_P1.3mm_Bridged12_Pad1.5x1.5mm_NumberLabels
U1: AMS1117-3.3; SOT-223-3_TabPin2

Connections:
+3.3VA: C1.1, CON1.2, CON2.2, J1.5, JP1.1 (A)
+3.3VP: C3.1, JP1.3 (B), U1.2 (VO)
+3V3: J2.5, JP1.2 (C)
+5V: C2.1, C4.1, J1.1, J1.2, J1.3, J2.1, J2.2, J2.3, J3.2, J4.2, U1.3 (VI)
/AN_CS0: J1.11, J2.11
/AN_CS1: J1.13, J2.13
/AN_CS2: J1.15, J2.15
/AN_CS3: J1.17, J2.17
/GP1: J1.23, J2.23
/GP6: CON1.3, CON2.3, J1.24, J2.24
/GP7: CON1.4, CON2.4, J1.22, J2.22
/GP8: J1.20, J2.20
/GP9: J1.18, J2.18
/GP10: J1.16, J2.16
/GP11: J1.14, J2.14
/GP12: J1.12, J2.12
/GP13: J1.10, J2.10
/GP14: J1.8, J2.8
/GP15: J1.6, J2.6
/GP16: J1.7, J2.7
/GP17: J1.9, J2.9
/MISO: J1.25, J2.25
/MOSI: J1.19, J2.19
/SCK: J1.21, J2.21
/SCL0: J1.26, J2.26
/SDA0: J1.28, J2.28
GND: C1.2, C2.2, C3.2, C4.2, CON1.1, CON2.1, J1.4, J1.27, J1.29, J1.30, J2.4, J2.27, J2.29, J2.30, J3.1, J4.1, U1.1 (GND)

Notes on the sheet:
| All | boards
| Dig In (I/O)
_____________ Serial Board
Analog __________
| Most | boards
Analog Power Mon __________
MONITOR EXPANSION BOARD MON-EX-06
Two mounting locations

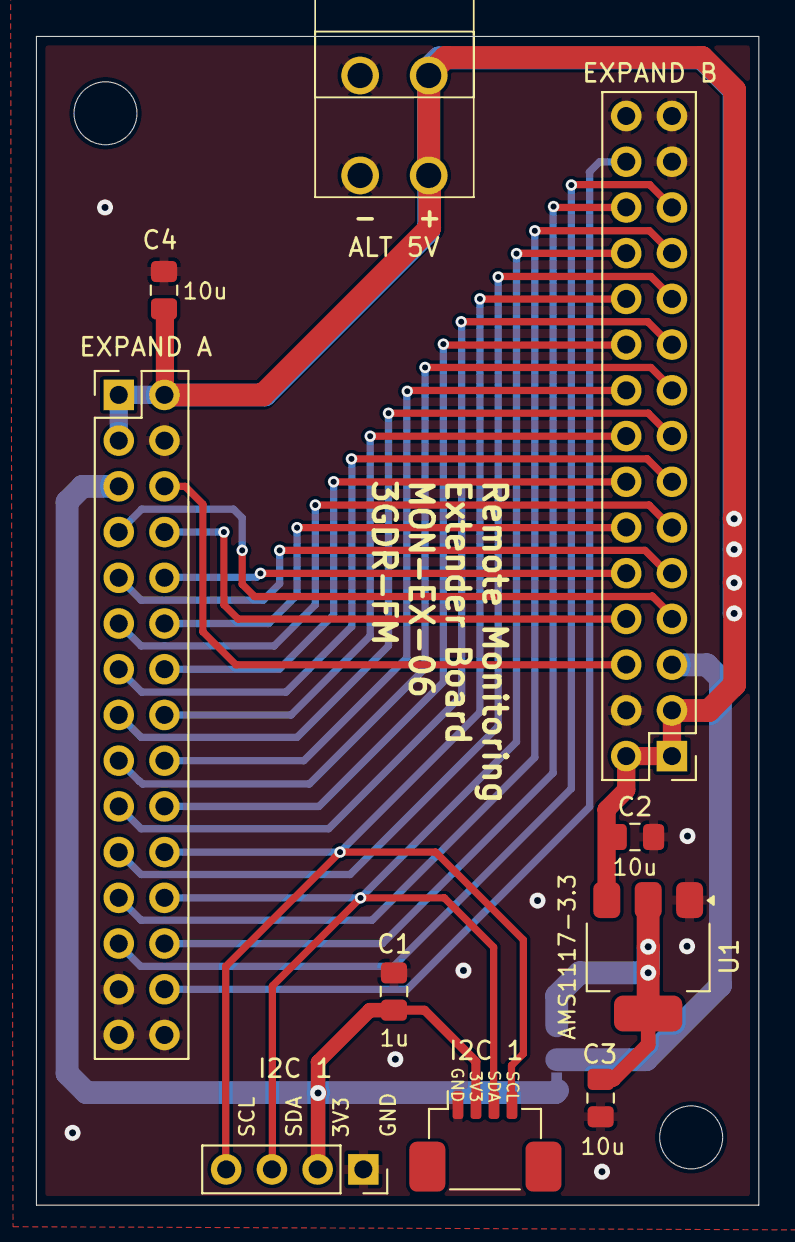
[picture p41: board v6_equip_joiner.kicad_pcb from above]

Board: 2 copper layers, 40.1 x 64.9 mm, 14 parts (1 on the bottom side), 27 nets.

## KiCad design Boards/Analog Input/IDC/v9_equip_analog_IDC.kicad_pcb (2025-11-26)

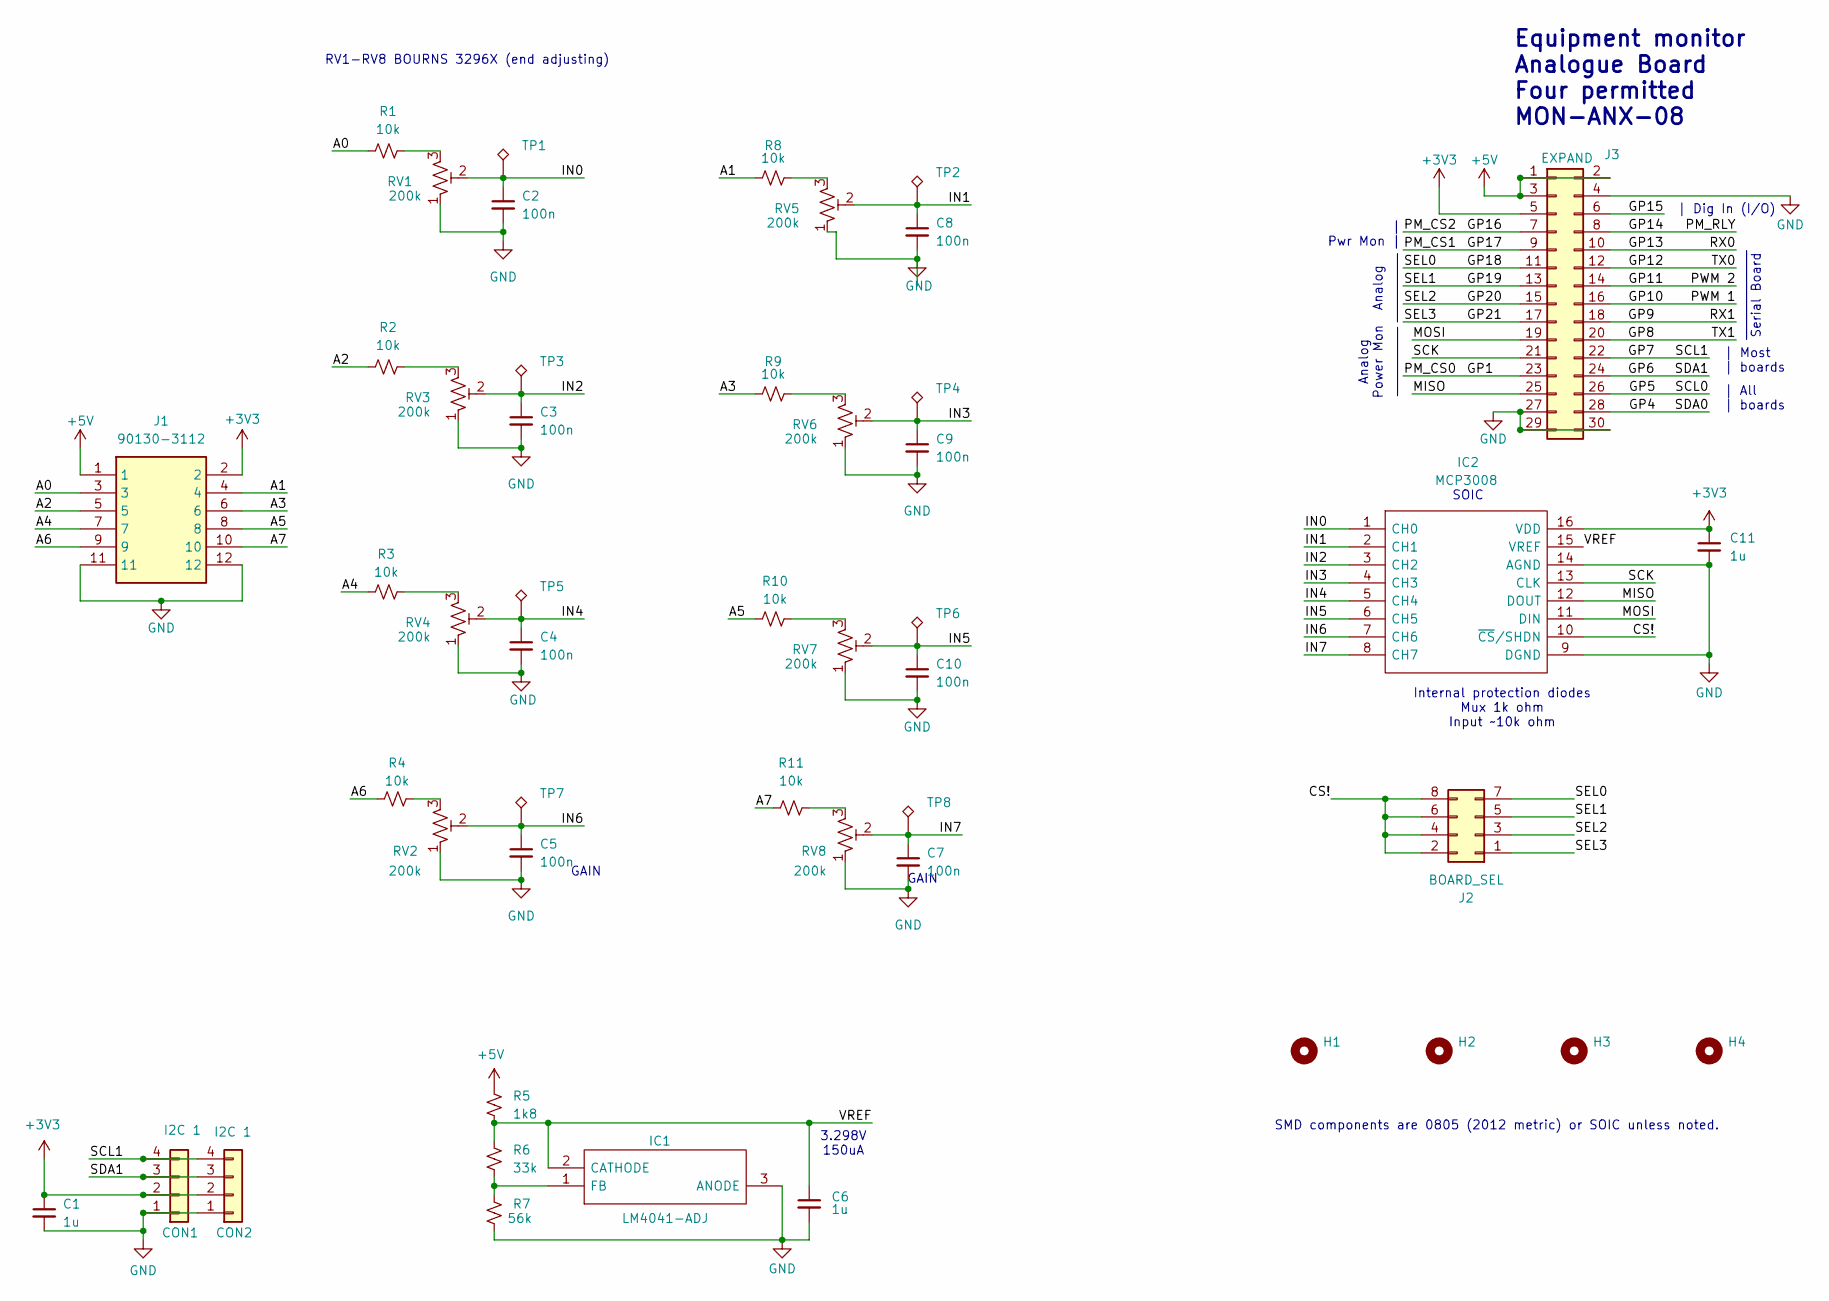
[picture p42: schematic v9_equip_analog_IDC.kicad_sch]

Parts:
C1, C6, C11: 1u; C_0805_2012Metric_Pad1.18x1.45mm_HandSolder
C2, C3, C4, C5, C7, C8, C9, C10: 100n; C_0805_2012Metric_Pad1.18x1.45mm_HandSolder
CON1: I2C 1; PinSocket_1x04_P2.54mm_Vertical
CON2: I2C 1; JST_SH_SM04B-SRSS-TB_1x04-1MP_P1.00mm_Horizontal_wide_MP
H1, H2, H3, H4: MountingHole; MountingHole_3.5mm_no_fill
IC1: LM4041-ADJ; SOT95P237X112-3N; Mouser Part Number 595-LM4041C12IDBZR
IC2: MCP3008; SOIC127P600X175-16N; Mouser Part Number 579-MCP3008-I/SL
J1: 90130-3112; SHDRRA12W65P254_2X6_1758X1090X1005P; Mouser Part Number 538-90130-3112
J2: BOARD_SEL; PinHeader_2x04_P2.54mm_Vertical
J3: EXPAND; PinHeader_2x15_P2.54mm_Vertical
R1, R2, R3, R4, R8, R9, R10, R11: 10k; R_0805_2012Metric_Pad1.20x1.40mm_HandSolder
R5: 1k8; R_0805_2012Metric_Pad1.20x1.40mm_HandSolder
R6: 33k; R_0805_2012Metric_Pad1.20x1.40mm_HandSolder
R7: 56k; R_0805_2012Metric_Pad1.20x1.40mm_HandSolder
RV1, RV2, RV3, RV4, RV5, RV6, RV7, RV8: 200k; Potentiometer_Bourns_3296X_Horizontal
TP1, TP2, TP3, TP4, TP5, TP6, TP7, TP8: TestPoint_Alt; TestPoint_THTPad_2.0x2.0mm_Drill1.0mm

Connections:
+3V3: C1.1, C11.1, CON1.2, CON2.2, IC2.16 (VDD), J1.2, J3.5
+5V: J1.1, J3.1, J3.2, J3.3, R5.1
/A0: J1.3, R1.1
/A1: J1.4, R8.1
/A2: J1.5, R2.1
/A3: J1.6, R9.1
/A4: J1.7, R3.1
/A5: J1.8, R10.1
/A6: J1.9, R4.1
/A7: J1.10, R11.1
/CS!: IC2.10 (~CS/SHDN), J2.2, J2.4, J2.6, J2.8
/GP1: J3.23
/GP4: J3.28
/GP5: J3.26
/GP6: CON1.3, CON2.3, J3.24
/GP7: CON1.4, CON2.4, J3.22
/GP8: J3.20
/GP9: J3.18
/GP10: J3.16
/GP11: J3.14
/GP12: J3.12
/GP13: J3.10
/GP14: J3.8
/GP15: J3.6
/GP16: J3.7
/GP17: J3.9
/GP18: J2.7, J3.11
/GP19: J2.5, J3.13
/GP20: J2.3, J3.15
/GP21: J2.1, J3.17
/IN0: C2.1, IC2.1 (CH0), RV1.2, TP1.1
/IN1: C8.1, IC2.2 (CH1), RV5.2, TP2.1
/IN2: C3.1, IC2.3 (CH2), RV3.2, TP3.1
/IN3: C9.1, IC2.4 (CH3), RV6.2, TP4.1
/IN4: C4.1, IC2.5 (CH4), RV4.2, TP5.1
/IN5: C10.1, IC2.6 (CH5), RV7.2, TP6.1
/IN6: C5.1, IC2.7 (CH6), RV2.2, TP7.1
/IN7: C7.1, IC2.8 (CH7), RV8.2, TP8.1
/MISO: IC2.12 (DOUT), J3.25
/MOSI: IC2.11 (DIN), J3.19
/SCK: IC2.13 (CLK), J3.21
/VREF: C6.1, IC1.2 (CATHODE), IC2.15 (VREF), R5.2, R6.1
GND: C1.2, C2.2, C3.2, C4.2, C5.2, C6.2, C7.2, C8.2, C9.2, C10.2, C11.2, CON1.1, CON2.1, IC1.3 (ANODE), IC2.9 (DGND), IC2.14 (AGND), J1.11, J1.12, J3.4, J3.27, J3.29, J3.30, R7.2, RV1.1, RV2.1, RV3.1, RV4.1, RV5.1, RV6.1, RV7.1, RV8.1
unnamed: IC1.1 (FB), R6.2, R7.1
unnamed: R1.2, RV1.3
unnamed: R2.2, RV3.3
unnamed: R3.2, RV4.3
unnamed: R4.2, RV2.3
unnamed: R8.2, RV5.3
unnamed: R9.2, RV6.3
unnamed: R10.2, RV7.3
unnamed: R11.2, RV8.3

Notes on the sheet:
GAIN
| Pwr Mon |
3.298V 150uA
SMD components are 0805 (2012 metric) or SOIC unless noted.
| Dig In (I/O)
Internal protection diodes Mux 1k ohm Input ~10k ohm
_____________ Serial Board
Equipment monitor Analogue Board Four permitted MON-ANX-08
SOIC
Analog Power Mon __________
Analog __________
| Most | boards
RV1-RV8 BOURNS 3296X (end adjusting)
| All | boards

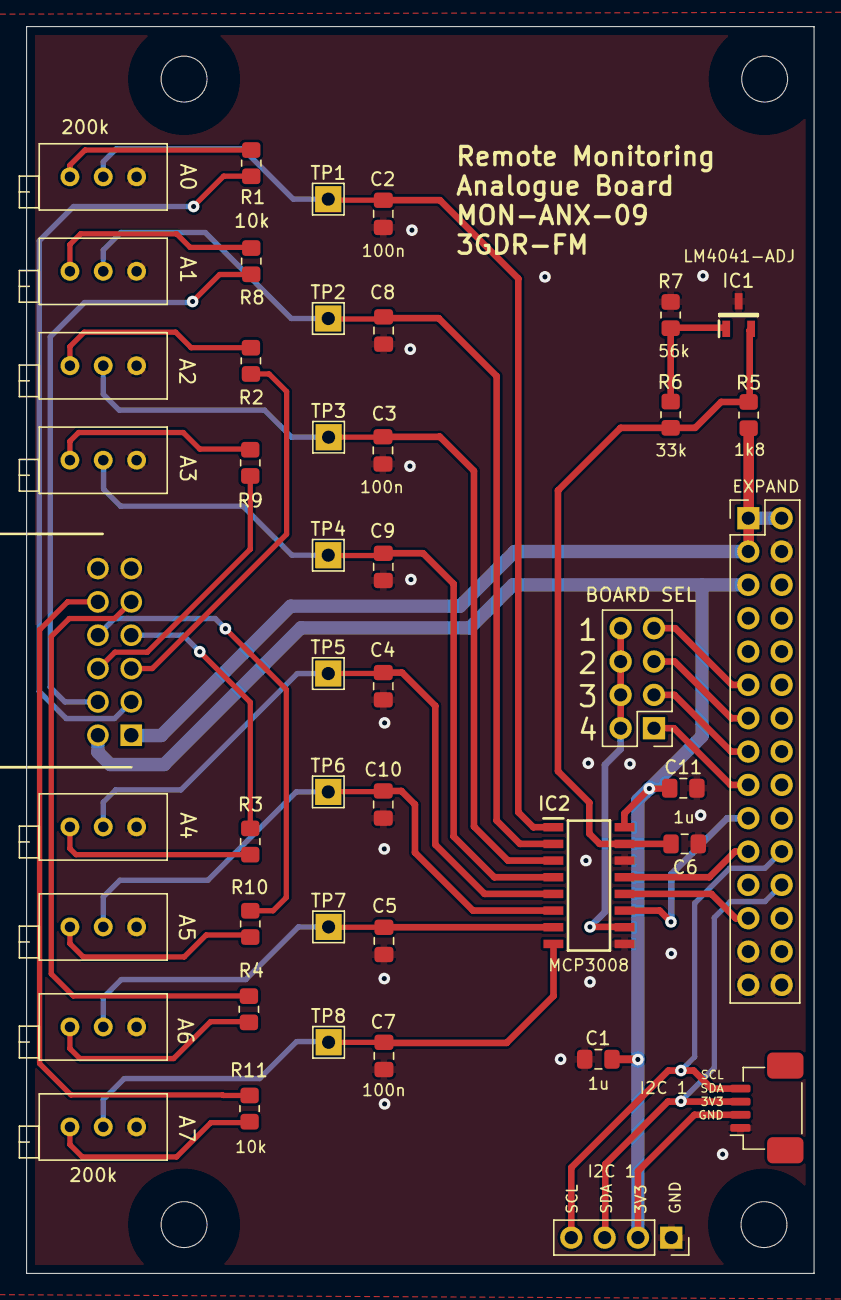
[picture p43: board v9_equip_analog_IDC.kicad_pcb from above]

Board: 2 copper layers, 60.0 x 95.0 mm, 49 parts (0 on the bottom side), 39 nets.

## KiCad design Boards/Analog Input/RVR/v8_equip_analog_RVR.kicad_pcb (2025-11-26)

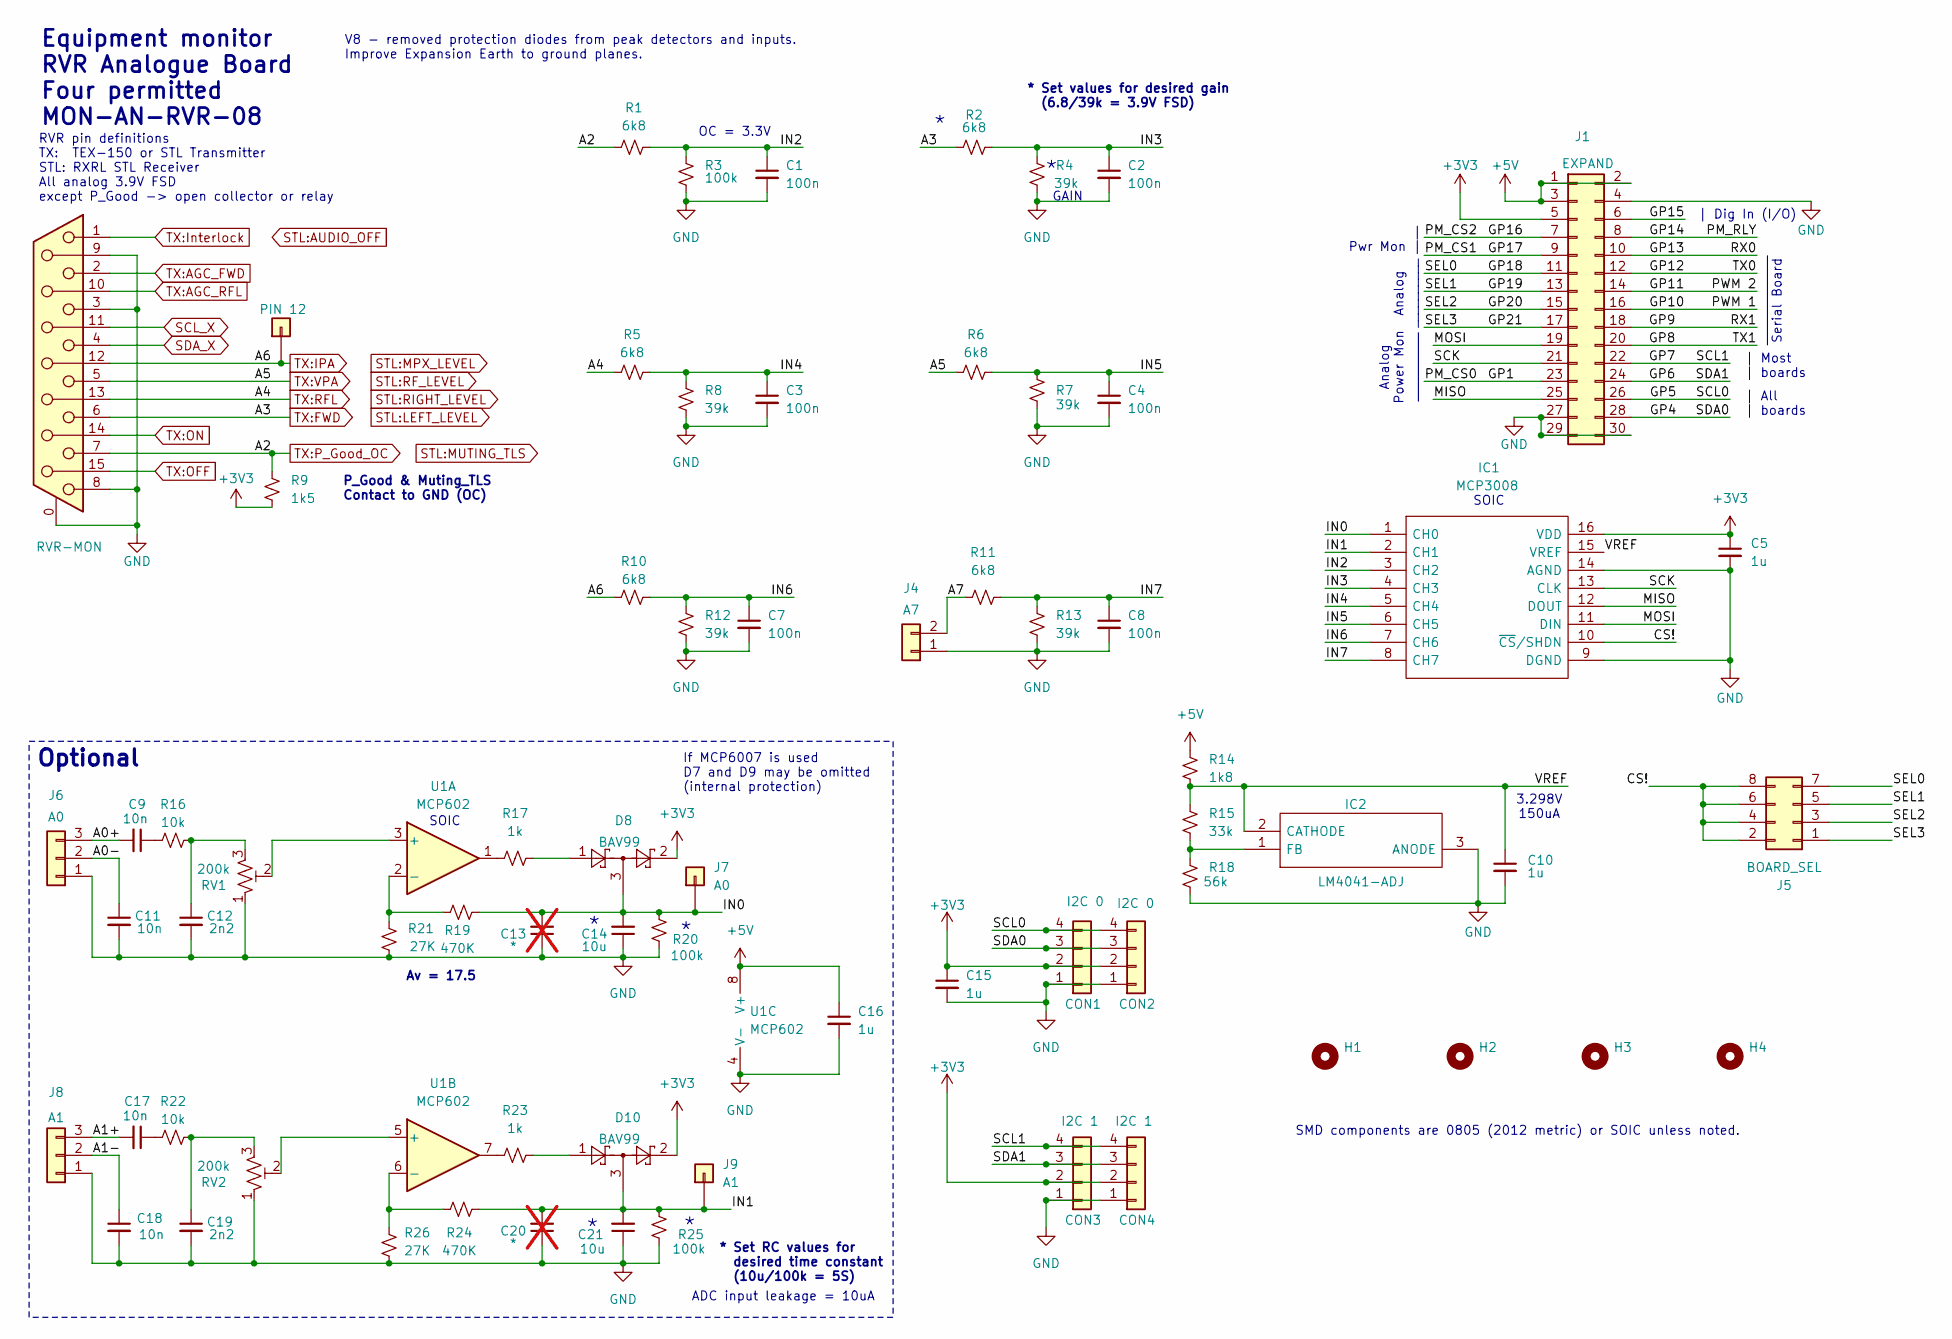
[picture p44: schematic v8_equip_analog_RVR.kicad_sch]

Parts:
C1, C2, C3, C4, C7, C8: 100n; C_0805_2012Metric_Pad1.18x1.45mm_HandSolder
C5, C10, C15, C16: 1u; C_0805_2012Metric_Pad1.18x1.45mm_HandSolder
C9, C11, C17, C18: 10n; C_0805_2012Metric_Pad1.18x1.45mm_HandSolder
C12, C19: 2n2; C_0805_2012Metric_Pad1.18x1.45mm_HandSolder
C13, C20: *; C_0805_2012Metric_Pad1.18x1.45mm_HandSolder; not fitted
C14, C21: 10u; C_0805_2012Metric_Pad1.18x1.45mm_HandSolder
CON1: I2C 0; PinSocket_1x04_P2.54mm_Vertical
CON2: I2C 0; JST_SH_SM04B-SRSS-TB_1x04-1MP_P1.00mm_Horizontal_wide_MP
CON3: I2C 1; PinSocket_1x04_P2.54mm_Vertical
CON4: I2C 1; JST_SH_SM04B-SRSS-TB_1x04-1MP_P1.00mm_Horizontal_wide_MP
D8, D10: BAV99; SOT-23
H1, H2, H3, H4: MountingHole; MountingHole_3.5mm_no_fill
IC1: MCP3008; SOIC127P600X175-16N; Mouser Part Number 579-MCP3008-I/SL
IC2: LM4041-ADJ; SOT95P237X112-3N; Mouser Part Number 595-LM4041C12IDBZR
J1: EXPAND; PinHeader_2x15_P2.54mm_Vertical
J2: PIN 12; PinHeader_1x01_P2.54mm_Vertical
J3: RVR-MON; DSUB-15_Female_Horizontal_P2.77x2.84mm_EdgePinOffset4.94mm_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
J4: A7; K2EDG
J5: BOARD_SEL; PinHeader_2x04_P2.54mm_Vertical
J6: A0; K3EDG
J7: A0; PinHeader_1x01_P2.54mm_Vertical
J8: A1; K3EDG
J9: A1; PinHeader_1x01_P2.54mm_Vertical
R1, R2, R5, R6, R10, R11: 6k8; R_0805_2012Metric_Pad1.20x1.40mm_HandSolder
R3, R20, R25: 100k; R_0805_2012Metric_Pad1.20x1.40mm_HandSolder
R4, R7, R8, R12, R13: 39k; R_0805_2012Metric_Pad1.20x1.40mm_HandSolder
R9: 1k5; R_0805_2012Metric_Pad1.20x1.40mm_HandSolder
R14: 1k8; R_0805_2012Metric_Pad1.20x1.40mm_HandSolder
R15: 33k; R_0805_2012Metric_Pad1.20x1.40mm_HandSolder
R16, R22: 10k; R_0805_2012Metric_Pad1.20x1.40mm_HandSolder
R17, R23: 1k; R_0805_2012Metric_Pad1.20x1.40mm_HandSolder
R18: 56k; R_0805_2012Metric_Pad1.20x1.40mm_HandSolder
R19, R24: 470K; R_0805_2012Metric_Pad1.20x1.40mm_HandSolder
R21, R26: 27K; R_0805_2012Metric_Pad1.20x1.40mm_HandSolder
RV1, RV2: 200k; Potentiometer_Bourns_3296X_Horizontal
U1: MCP602; SO-8_3.9x4.9mm_P1.27mm

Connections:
+3V3: C5.1, C15.1, CON1.2, CON2.2, CON3.2, CON4.2, D8.2, D10.2, IC1.16 (VDD), J1.5, R9.1
+5V: C16.1, J1.1, J1.2, J1.3, R14.1, U1.8 (V+)
/A0+: C9.2, J6.3
/A0-: C11.1, J6.2
/A1+: C17.2, J8.3
/A1-: C18.1, J8.2
/A7: J4.2, R11.1
/CS!: IC1.10 (~CS/SHDN), J5.2, J5.4, J5.6, J5.8
/GP1: J1.23
/GP4: CON1.3, CON2.3, J1.28
/GP5: CON1.4, CON2.4, J1.26
/GP6: CON3.3, CON4.3, J1.24
/GP7: CON3.4, CON4.4, J1.22
/GP8: J1.20
/GP9: J1.18
/GP10: J1.16
/GP11: J1.14
/GP12: J1.12
/GP13: J1.10
/GP14: J1.8
/GP15: J1.6
/GP16: J1.7
/GP17: J1.9
/GP18: J1.11, J5.7
/GP19: J1.13, J5.5
/GP20: J1.15, J5.3
/GP21: J1.17, J5.1
/IN0: C13.2, C14.2, D8.3, IC1.1 (CH0), J7.1, R19.2, R20.2
/IN1: C20.2, C21.2, D10.3, IC1.2 (CH1), J9.1, R24.2, R25.2
/IN2: C1.1, IC1.3 (CH2), R1.2, R3.1
/IN3: C2.1, IC1.4 (CH3), R2.2, R4.1
/IN4: C3.1, IC1.5 (CH4), R5.2, R8.1
/IN5: C4.1, IC1.6 (CH5), R6.2, R7.1
/IN6: C7.1, IC1.7 (CH6), R10.2, R12.1
/IN7: C8.1, IC1.8 (CH7), R11.2, R13.1
/MISO: IC1.12 (DOUT), J1.25
/MOSI: IC1.11 (DIN), J1.19
/SCK: IC1.13 (CLK), J1.21
/VREF: C10.1, IC1.15 (VREF), IC2.2 (CATHODE), R14.2, R15.1
GND: C1.2, C2.2, C3.2, C4.2, C5.2, C7.2, C8.2, C10.2, C11.2, C12.2, C13.1, C14.1, C15.2, C16.2, C18.2, C19.2, C20.1, C21.1, CON1.1, CON2.1, CON3.1, CON4.1, IC1.9 (DGND), IC1.14 (AGND), IC2.3 (ANODE), J1.4, J1.27, J1.29, J1.30, J3.0 (PAD), J3.3, J3.8, J3.9, J4.1, J6.1, J8.1, R3.2, R4.2, R7.2, R8.2, R12.2, R13.2, R18.2, R20.1, R21.1, R25.1, R26.1, RV1.1, RV2.1, U1.4 (V-)
unnamed: C9.1, R16.1
unnamed: C12.1, R16.2, RV1.3
unnamed: C17.1, R22.1
unnamed: C19.1, R22.2, RV2.3
unnamed: D8.1, R17.2
unnamed: D10.1, R23.2
unnamed: IC2.1 (FB), R15.2, R18.1
unnamed: R17.1, U1.1
unnamed: R23.1, U1.7
unnamed: RV1.2, U1.3 (+)
unnamed: R19.1, R21.2, U1.2 (-)
unnamed: RV2.2, U1.5 (+)
unnamed: R24.1, R26.2, U1.6 (-)
SCL_X: J3.11 (P111)
SDA_X: J3.4
TX:AGC_FWD: J3.2
TX:AGC_RFL: J3.10
TX:FWD: J3.6, R2.1
TX:IPA: J2.1, J3.12, R10.1
TX:Interlock: J3.1
TX:OFF: J3.15
TX:ON: J3.14
TX:P_Good_OC: J3.7, R1.1, R9.2
TX:RFL: J3.13, R5.1
TX:VPA: J3.5, R6.1

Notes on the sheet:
GAIN
| Pwr Mon |
3.298V 150uA
OC = 3.3V
SOIC
V8 - removed protection diodes from peak detectors and inputs. Improve Expansion Earth to ground planes.
Av = 17.5
SMD components are 0805 (2012 metric) or SOIC unless noted.
| Dig In (I/O)
* Set values for desired gain (6.8/39k = 3.9V FSD)
_____________ Serial Board
P_Good & Muting_TLS Contact to GND (OC)
If MCP6007 is used D7 and D9 may be omitted (internal protection)
Optional
Equipment monitor RVR Analogue Board Four permitted MON-AN-RVR-08
ADC input leakage = 10uA
Analog Power Mon __________
Analog __________
RVR pin definitions TX: TEX-150 or STL Transmitter STL: RXRL STL Receiver All analog 3.9V FSD except P_Good -> open collector or relay
| Most | boards
* Set RC values for desired time constant (10u/100k = 5S)
| All | boards


Board: 2 copper layers, 60.0 x 95.0 mm, 70 parts (0 on the bottom side), 47 nets.

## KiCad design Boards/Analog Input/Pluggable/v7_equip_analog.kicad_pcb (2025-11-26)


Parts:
C1, C3, C4, C5, C7, C8, C11, C12: 100n; C_0805_2012Metric_Pad1.18x1.45mm_HandSolder
C2, C6, C9, C10, C13: 1u; C_0805_2012Metric_Pad1.18x1.45mm_HandSolder
CON1: I2C 1; PinSocket_1x04_P2.54mm_Vertical
CON2: I2C 1; JST_SH_SM04B-SRSS-TB_1x04-1MP_P1.00mm_Horizontal_wide_MP
D1, D2, D3, D4, D5, D6, D7, D8: BAV99; SOT-23
H1, H2, H3, H4: MountingHole; MountingHole_3.5mm_no_fill
IC1: MCP3008; SOIC127P600X175-16N; Mouser Part Number 579-MCP3008-I/SL
IC2: LM4041-ADJ; SOT95P237X112-3N; Mouser Part Number 595-LM4041C12IDBZR
J1, J5, J7, J9: IN 2; K2EDG; Mouser Part Number 649-220110-D021A01LF
J2, J4, J6, J10: A7; K2EDG
J3: EXPAND; PinHeader_2x15_P2.54mm_Vertical
J8: BOARD_SEL; PinHeader_2x04_P2.54mm_Vertical
R1, R2, R3, R4, R5, R6, R10, R11: 10k; R_0805_2012Metric_Pad1.20x1.40mm_HandSolder
R7: 1k8; R_0805_2012Metric_Pad1.20x1.40mm_HandSolder
R8: 33k; R_0805_2012Metric_Pad1.20x1.40mm_HandSolder
R9: 56k; R_0805_2012Metric_Pad1.20x1.40mm_HandSolder
RV1, RV2, RV3, RV4, RV5, RV6, RV7, RV8: 200k; Potentiometer_Bourns_3296X_Horizontal

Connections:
+3V3: C2.1, C6.1, C10.1, C13.1, CON1.2, CON2.2, D1.2, D2.2, D3.2, D4.2, D5.2, D6.2, D7.2, D8.2, IC1.16 (VDD), J3.5
+5V: J3.1, J3.2, J3.3, R7.1
/A0: J1.2, R1.1
/A1: J2.2, R2.1
/A2: J5.2, R4.1
/A3: J4.2, R3.1
/A4: J7.2, R6.1
/A5: J6.2, R5.1
/A6: J9.2, R10.1
/A7: J10.2, R11.1
/CS!: IC1.10 (~CS/SHDN), J8.2, J8.4, J8.6, J8.8
/GP1: J3.23
/GP4: J3.28
/GP5: J3.26
/GP6: CON1.3, CON2.3, J3.24
/GP7: CON1.4, CON2.4, J3.22
/GP8: J3.20
/GP9: J3.18
/GP10: J3.16
/GP11: J3.14
/GP12: J3.12
/GP13: J3.10
/GP14: J3.8
/GP15: J3.6
/GP16: J3.7
/GP17: J3.9
/GP18: J3.11, J8.7
/GP19: J3.13, J8.5
/GP20: J3.15, J8.3
/GP21: J3.17, J8.1
/IN0: C1.1, D1.3, IC1.1 (CH0), RV1.2
/IN1: C3.1, D2.3, IC1.2 (CH1), RV2.2
/IN2: C5.1, D4.3, IC1.3 (CH2), RV4.2
/IN3: C4.1, D3.3, IC1.4 (CH3), RV3.2
/IN4: C8.1, D6.3, IC1.5 (CH4), RV6.2
/IN5: C7.1, D5.3, IC1.6 (CH5), RV5.2
/IN6: C11.1, D7.3, IC1.7 (CH6), RV7.2
/IN7: C12.1, D8.3, IC1.8 (CH7), RV8.2
/MISO: IC1.12 (DOUT), J3.25
/MOSI: IC1.11 (DIN), J3.19
/SCK: IC1.13 (CLK), J3.21
/VREF: C9.1, IC1.15 (VREF), IC2.2 (CATHODE), R7.2, R8.1
GND: C1.2, C2.2, C3.2, C4.2, C5.2, C6.2, C7.2, C8.2, C9.2, C10.2, C11.2, C12.2, C13.2, CON1.1, CON2.1, D1.1, D2.1, D3.1, D4.1, D5.1, D6.1, D7.1, D8.1, IC1.9 (DGND), IC1.14 (AGND), IC2.3 (ANODE), J1.1, J2.1, J3.4, J3.27, J3.29, J3.30, J4.1, J5.1, J6.1, J7.1, J9.1, J10.1, R9.2, RV1.1, RV2.1, RV3.1, RV4.1, RV5.1, RV6.1, RV7.1, RV8.1
unnamed: IC2.1 (FB), R8.2, R9.1
unnamed: R1.2, RV1.3
unnamed: R2.2, RV2.3
unnamed: R3.2, RV3.3
unnamed: R4.2, RV4.3
unnamed: R5.2, RV5.3
unnamed: R6.2, RV6.3
unnamed: R10.2, RV7.3
unnamed: R11.2, RV8.3

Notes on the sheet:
GAIN
| Pwr Mon |
3.298V 150uA
SMD components are 0805 (2012 metric) or SOIC unless noted.
| Dig In (I/O)
_____________ Serial Board
Equipment monitor Analogue Board Four permitted MON-AN-07
SOIC
Analog Power Mon __________
Analog __________
| Most | boards
RV1-RV8 BOURNS 3296X (end adjusting)
| All | boards


Board: 2 copper layers, 60.0 x 95.0 mm, 58 parts (0 on the bottom side), 39 nets.

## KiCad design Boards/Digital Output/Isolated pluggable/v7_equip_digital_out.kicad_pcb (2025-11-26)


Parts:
C1, C3, C4: 1u; C_0805_2012Metric_Pad1.18x1.45mm_HandSolder
C2, C5: 10u; C_0805_2012Metric_Pad1.18x1.45mm_HandSolder
CON1: I2C 0; PinSocket_1x04_P2.54mm_Vertical
CON2: I2C 0; JST_SH_SM04B-SRSS-TB_1x04-1MP_P1.00mm_Horizontal_wide_MP
D1, D2: BAT54C; SOT-23
H1, H2, H3, H4: MountingHole; MountingHole_3.5mm_no_fill
IC1: PCA9554-DWR; SOIC127P1030X265-16N; Mouser Part Number 595-PCA9534DWR
J1: RELAY 1; K3EDG; Mouser Part Number 649-220110-D031A01LF
J2: RELAY 2; K3EDG; Mouser Part Number 649-220110-D031A01LF
J3: OPTO 5; K2EDG; Mouser Part Number 649-220110-D021A01LF
J5: OPTO 6; K2EDG; Mouser Part Number 649-220110-D021A01LF
J6: EXPAND; PinHeader_2x15_P2.54mm_Vertical
J7: OPTO 7; K2EDG; Mouser Part Number 649-220110-D021A01LF
J8: RELAY 3; K3EDG; Mouser Part Number 649-220110-D031A01LF
J9: RELAY 4; K3EDG; Mouser Part Number 649-220110-D031A01LF
J10: OPTO 8; K2EDG; Mouser Part Number 649-220110-D021A01LF
J11: RELAY; PinHeader_2x06_P2.54mm_Vertical
JP1: A0; PinHeader_1x03_P2.54mm_Vertical
JP2: A1; PinHeader_1x03_P2.54mm_Vertical
K1, K2, K3, K4: G5V-2_H1; Relay_DPDT_Omron_G5V-2_BIGGER_HOLES
Q1, Q2, Q3, Q4, Q5, Q6, Q7, Q8: BC817; SOT-23
R1, R3, R7, R9: 220; R_0805_2012Metric_Pad1.20x1.40mm_HandSolder
R2, R4, R5, R6, R8, R10, R11, R12: 10k; R_0805_2012Metric_Pad1.20x1.40mm_HandSolder
U1, U2, U3, U4: PC-817; SOP254P960X420-4N

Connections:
+3V3: C1.1, C3.1, CON1.2, CON2.2, IC1.16 (VCC), J6.5, JP1.3 (B), JP2.3 (B)
+5V: C2.1, C4.1, C5.1, D1.3, D2.3, J6.1, J6.2, J6.3, J11.1, J11.2, J11.11, J11.12, K1.16, K2.16, K3.1, K4.16, R1.2, R3.2, R7.2, R9.2
/A0: IC1.1 (A0), JP1.2 (C)
/A1: IC1.2 (A1), JP2.2 (C)
/AN_CS0: J6.11
/AN_CS1: J6.13
/AN_CS2: J6.15
/AN_CS3: J6.17
/GP1: J6.23
/GP6: J6.24
/GP7: J6.22
/GP8: J6.20
/GP9: J6.18
/GP10: J6.16
/GP11: J6.14
/GP12: J6.12
/GP13: J6.10
/GP14: J6.8
/GP15: J6.6
/GP16: J6.7
/GP17: J6.9
/MISO: J6.25
/MOSI: J6.19
/P0: IC1.4 (P0), J11.3, R6.1
/P1: IC1.5 (P1), J11.5, R5.1
/P2: IC1.6 (P2), J11.7, R11.1
/P3: IC1.7 (P3), J11.9, R12.1
/P4: IC1.9 (P4), R2.1
/P5: IC1.10 (P5), R4.1
/P6: IC1.11 (P6), R8.1
/P7: IC1.12 (P7), R10.1
/SCK: J6.21
/SCL0: CON1.4, CON2.4, IC1.14 (SCL), J6.26
/SDA0: CON1.3, CON2.3, IC1.15 (SDA), J6.28
GND: C1.2, C2.2, C3.2, C4.2, C5.2, CON1.1, CON2.1, IC1.3 (A2), IC1.8 (GND), J6.4, J6.27, J6.29, J6.30, J11.4, J11.6, J11.8, J11.10, JP1.1 (A), JP2.1 (A), Q1.2 (E), Q2.2 (E), Q3.2 (E), Q4.2 (E), Q5.2 (E), Q6.2 (E), Q7.2 (E), Q8.2 (E)
unnamed: J1.1, K1.6, K1.11
unnamed: J1.2, K1.4, K1.13
unnamed: J1.3, K1.8, K1.9
unnamed: J2.1, K2.6, K2.11
unnamed: J2.2, K2.4, K2.13
unnamed: J2.3, K2.8, K2.9
unnamed: J3.1, U1.3
unnamed: J3.2, U1.4
unnamed: J5.1, U2.3
unnamed: J5.2, U2.4
unnamed: J7.1, U3.3
unnamed: J7.2, U3.4
unnamed: J8.1, K3.6, K3.11
unnamed: J8.2, K3.4, K3.13
unnamed: J8.3, K3.8, K3.9
unnamed: J9.1, K4.6, K4.11
unnamed: J9.2, K4.4, K4.13
unnamed: J9.3, K4.8, K4.9
unnamed: J10.1, U4.3
unnamed: J10.2, U4.4
unnamed: Q1.1 (B), R2.2
unnamed: Q1.3 (C), U1.2
unnamed: Q2.1 (B), R4.2
unnamed: Q2.3 (C), U2.2
unnamed: Q3.1 (B), R5.2
unnamed: D1.2, K2.1, Q3.3 (C)
unnamed: Q4.1 (B), R6.2
unnamed: D1.1, K1.1, Q4.3 (C)
unnamed: Q5.1 (B), R8.2
unnamed: Q5.3 (C), U3.2
unnamed: Q6.1 (B), R10.2
unnamed: Q6.3 (C), U4.2
unnamed: Q7.1 (B), R11.2
unnamed: D2.1, K3.16, Q7.3 (C)
unnamed: Q8.1 (B), R12.2
unnamed: D2.2, K4.1, Q8.3 (C)
unnamed: R1.1, U1.1
unnamed: R3.1, U2.1
unnamed: R7.1, U3.1
unnamed: R9.1, U4.1

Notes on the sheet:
| Dig In (I/O)
Analog __________
1A @ 24VDC
| Pwr Mon |
Match with Amphenol TJ 3.81mm See Altronics P2673 / P2653
Equipment monitor Digital Output Board MON-DO-07 Four permitted
Sensitive (low coil curent) OMRON G5V-2_H1 Altronics S4147
| All | boards
SMD components are 0805 (2012 metric) or SOIC unless noted.
| Most | boards
Analog Power Mon __________
_____________ Serial Board

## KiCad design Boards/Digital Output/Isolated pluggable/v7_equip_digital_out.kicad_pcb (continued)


Board: 2 copper layers, 60.0 x 95.0 mm, 54 parts (0 on the bottom side), 55 nets.

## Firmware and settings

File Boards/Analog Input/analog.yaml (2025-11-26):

spi:
#  - id: spi_bus0
  clk_pin: 2
  mosi_pin: 3
  miso_pin: 0
 
mcp3008:    # for three boards
  - id: mcp0  # A
    cs_pin: 18
    data_rate: 200kHz

  - id: mcp1  # B
    cs_pin: 19
    data_rate: 200kHz

  - id: mcp2  # C
    cs_pin: 20
    data_rate: 200kHz
    
sensor:
# Analog input is trimmable, so volts value is arbitrary unless calibrated
# Ch 0, Board A, Scaled to % FSD
  - platform: mcp3008
    mcp3008_id: mcp0
    unit_of_measurement: "%"
    reference_voltage: 3.0  
    update_interval: 5s
    name: "Analog Input 0 (%)" 
    accuracy_decimals: 1
    id: analog_in0
    number: 0     
    filters:   
      - multiply: !lambda return 33.3; # 100%

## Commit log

2025-11-26 New files
    [v6_equip_joiner-B_Cu.gbr, v6_equip_joiner-B_Mask.gbr, v6_equip_joiner-B_Paste.gbr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]
2025-11-26 update files
    [bar holder.stl, base.stl, middle.stl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]
2025-11-26 Update case lid.svg
